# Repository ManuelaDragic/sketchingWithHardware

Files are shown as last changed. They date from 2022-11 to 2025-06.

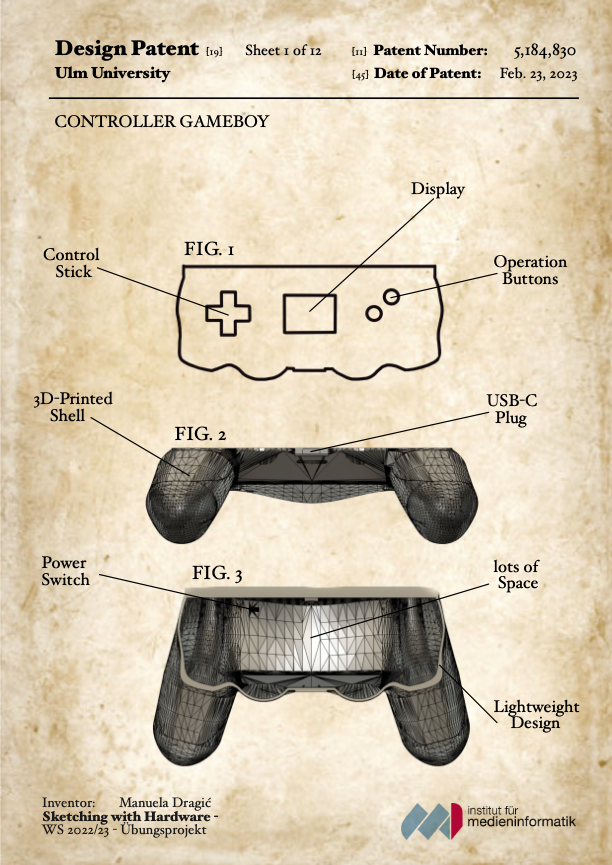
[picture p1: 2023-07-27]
content/posts/pictures/Poster.png

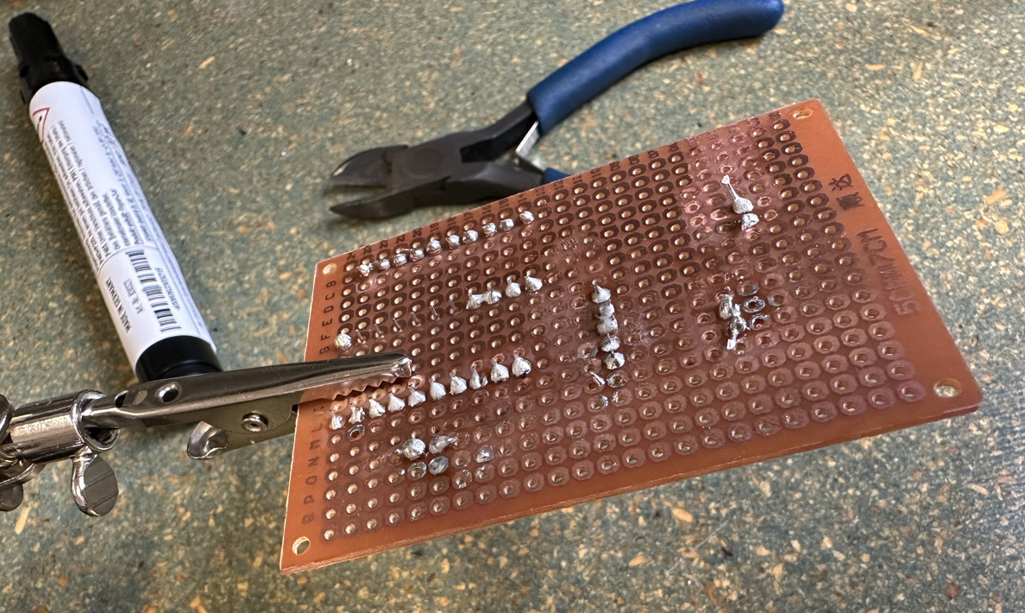
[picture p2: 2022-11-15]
content/posts/pictures/resultat.png

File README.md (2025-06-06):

# Sketching with Hardware

## Project of the applied subject in Media Informatics at Ulm University

During the winter semester 2022/23 and summer semester 2023. 
The blog can be found at: [(https://manueladragic.github.io/swh/)](https://manueladragic.github.io/swh/)

The files folder contains all the files necessary for rebuilding the WordClock Project.

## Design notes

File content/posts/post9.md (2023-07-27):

---
title: "02. Nachbauanleitung - WordClockanazier"
date: 2023-07-24T00:08:16+02:00
featured_image: "/pictures/wordclock.jpeg"
show_reading_time: true
draft: false
---

Eine WordClock ist eine Uhr, die anstelle von Zahlen Wörter oder Buchstaben verwendet, um die Uhrzeit anzuzeigen. 
Indem die WordClock mit einem intelligenten Kalender verknüpft wird, hilft sie dabei die Uhrzeit im Blick zu behalten und gleichzeitig über anstehende Termine informiert zu sein.
Daneben bietet der "WordClockanazier" weitere Features wie einen Farbwechselbutton, ein Ambient-Light und eine automatische Helligkeitsanpassung.
Einzelne Komponenten wie das Ambient-Light oder der Kalender können zudem beliebig ein- und ausgeschaltet werden. 
Betrieben wird die Uhr mit einem 5V Netzteil. 

Die Kosten für das Projekt betragen etwa 50 Euro.

{{< figure src="../pictures/Wordclock.jpeg" width="60%"height="60%">}}
{{< figure src="../pictures/Rahmen_oben(neu).jpeg" width="60%"height="60%">}}
{{< figure src="../pictures/Rahmen_rechts(neu).jpeg" width="60%"height="60%">}}
{{< figure src="../pictures/Rahmen_links(neu).jpeg" width="60%"height="60%">}}
{{< rawhtml >}} 
<video width=60% controls autoplay>
    <source src="../pictures/Funktionen.mp4" type="video/mp4">
    Your browser does not support the video tag.  
</video>
{{< /rawhtml >}}

</br>

### Bauteile, Zubehör und benötigte Programme

#### Technik:
- [ ] Wemos D1 mini 
- [ ] RTC Modul
- [ ] Knopf Batterie (für RTC Modul)
- [ ] 3m LED Stripe (60 LEDs pro Meter)
- [ ] 3x 4in1 Led Matrizen 
- [ ] USB auf Mikro USB Kabel (zum uploaden des Codes)

#### Materialien:
- [ ] Verschiedene Kabel (rot, schwarz, lila, blau, gelb, grün, braun)
- [ ] Schrumpfschläuche
- [ ] 3x Platine 2x8cm
- [ ] 1x Platine 6x8cm
- [ ] 3x Button groß (1cm x 1cm)
- [ ] 3x Buttonkappe (schwarz)
- [ ] Helligkeitssensor
- [ ] 2x Diode
- [ ] 1x Widerstand 2,2kOhm
- [ ] 1x Widerstand 4,7 kOhm
- [ ] 2x Widerstand 470 Ohm
- [ ] 1x ON/OFF Kippschalter
- [ ] 5V Adapter
- [ ] 5V 3A Netzteil
- [ ] 4 Senkkopfschrauben (3mm Durchmesser, 12mm lang)
- [ ] 4 Schrauben Fassungen (3mm Durchmesser, 5mm lang)

{{< figure src="../pictures/bauteile.jpeg" width="100%"height="80%">}}

#### Sonstiges:
- [ ] 2 x 3 mm dicke Spanplatte (mindestens 30x30cm groß)
- [ ] Durchsichtiges Filament (PLA)
- [ ] Schwarzes Filament (PLA)
- [ ] Doppelseitiges Klebeband
- [ ] 2 Komponenten Kleber

#### Geräte:
- [ ] großer 3D Drucker
- [ ] Lasercutter
- [ ] Lötkolben und -zubehör
- [ ] Bandsäge, Stichsäge oder eine andere Säge
- [ ] kleiner Schraubenzieher

#### Programme: 
- [ ] Arduino IDE
- [ ] Lightburn 
- [ ] (Fusion 360)
- [ ] (UltiMaker Cura)

#### Bauteile zu Cutten:
- [ ] Buchstabenplatte (3mm Spanplatte)
- [ ] LED Halterung (3mm Spanplatte)
- [ ] Holzfurnier (Buche)

#### Bauteile zu Drucken:
- [ ] Matrizenhalterung (Schwarz)
- [ ] Rahmen (Schwarz)
- [ ] Raster (Schwarz)
- [ ] Rasterfüllung (Durchsichtig)
- [ ] Rückplatte (Durchsichtig)

#### Zum testen:
- [ ] Steckplatine
- [ ] Jumperkabel

</br>

### Dateien zum Download

#### 3D-Modelle (STL's):
- <a href="https://github.com/ManuelaDragic/swh/blob/main/files/Matrizenhalterung.stl" download>Matrizenhalterung</a>
- <a href="https://github.com/ManuelaDragic/swh/blob/main/files/Word%20Clock%20Rahmen.stl" download>Rahmen</a>
- <a href="https://github.com/ManuelaDragic/swh/blob/main/files/WordClock%20Raster.stl"    download>Raster</a>
- <a href="https://github.com/ManuelaDragic/swh/blob/main/files/WordClock%20Rasterfüllung.stl" download>Rasterfüllung</a>
- <a href="https://github.com/ManuelaDragic/swh/blob/main/files/WordClock%20Rueckplatte.stl" download>Rückplatte</a>

#### Fusion360 Dateien:
- <a href="https://github.com/ManuelaDragic/swh/blob/main/files/Matrizenhalterung.f3d" download>Matrizenhalterung</a>
- <a href="https://github.com/ManuelaDragic/swh/blob/main/files/Word%20Clock%20Rahmen.f3d" download>Rahmen</a>
- <a href="https://github.com/ManuelaDragic/swh/blob/main/files/WordClock%20Raster.f3d"    download>Raster</a>
- <a href="https://github.com/ManuelaDragic/swh/blob/main/files/WordClock%20Rasterfüllung.f3d" download>Rasterfüllung</a>
- <a href="https://github.com/ManuelaDragic/swh/blob/main/files/WordClock%20Rueckplatte.f3d" download>Rückplatte</a>

#### Lightburn Datei:
- <a href="https://github.com/ManuelaDragic/swh/blob/main/files/Lasercut.lbrn2" download>Lasercut</a>

#### SVG:
- <a href="https://github.com/ManuelaDragic/swh/blob/main/files/Lasercut.svg" download>SVG Lasercut</a>

#### Code:
- <a href="https://github.com/ManuelaDragic/swh/blob/main/code/Kalender.gs" download>GoogleSkript</a>
- <a href="https://github.com/ManuelaDragic/swh/blob/main/code/WordClock/WordClock.ino" download>Arduino Code</a>
- <a href="https://github.com/ManuelaDragic/swh/blob/main/code/WordClock/WordClockFont.h" download>WordClock Font</a>

#### Links:
- <a href="https://script.google.com" download>Google Apps Skript</a>
- <a href="https://workspace.google.com/products/calendar/?hl=de#" download>Google Kalender</a>

</br>

### Lötplan

{{< figure src="../pictures/loetplan.jpg" width="100%"height="80%">}}

</br>

### Schritt für Schritt Bauanleitung

#### 1. Drucken der Bauteile

Zunächst einmal müssen die verschiedenen Bauteile gedruckt werden. Die zugehörigen STL's können auf meinem <a href="https://github.com/ManuelaDragic/swh/tree/main/files" download>Github</a> heruntergeladen werden, sind oben aber nochmals verlinkt.
Wichtig ist, dass für den Rahmen und die Rückplatte ein großer Drucker benötigt wird, da die Bauteile später ca. 25x35cm groß werden.
(Ich verwendete dazu den Creality CR10S5).
Der <a href="https://github.com/ManuelaDragic/swh/blob/main/files/Word%20Clock%20Rahmen.stl" download>Rahmen</a> des WordClockanizers, die <a href="https://github.com/ManuelaDragic/swh/blob/main/files/Matrizenhalterung.stl" download>Matrizenhalterung</a> und das <a href="https://github.com/ManuelaDragic/swh/blob/main/files/WordClock%20Raster.f3d"    download>Raster</a> werden mit schwarzem PLA gedruckt. Für die <a href="https://github.com/ManuelaDragic/swh/blob/main/files/WordClock%20Rasterfüllung.f3d" download>Rasterfüllung</a> und die <a href="https://github.com/ManuelaDragic/swh/blob/main/files/WordClock%20Rueckplatte.f3d" download>Rückplatte</a> wird durchsichtiges PLA verwendet.
Falls die Modelle noch angepasst werden sollen, können die jeweiligen Fusion360 Dateien ebenfalls oben heruntergeladen werden.

{{< figure src="../pictures/druck_schwarz.jpeg" width="100%"height="80%">}}
{{< figure src="../pictures/druck_durchsichtig.jpeg" width="100%"height="80%">}}

#### 2. Lasercutten

Danach werden die Buchstabenplatte und die LED-Stripe Halterung gecuttet. Dazu verwendete ich Lightburn. Zur leichteren Anpassung habe ich alle Linien des Cuts in eine <a href="https://github.com/ManuelaDragic/swh/blob/main/files/Lasercut.lbrn2" download>Datei</a> zusammengefügt. Für die Buchstabenplatte werden das innere Rechteck und die Buchstaben benötigt. Für die LED-Stripe Halterung werden das innere Rechteck und die schrägen Cuts an der linken und rechten Seite benötigt. Die jeweils anderen Linien können in Lightburn einfach ausgeblendet und ausgeschaltet werden.
Für die beiden Komponenten habe ich zwei 3mm dicke Spanplatten verwendet. Um sicher zu gehen sollten diese ca. 30x30cm groß sein. 

Die Vorderseite der Wordclock besteht aus ca 0,4 mm dickem Holzfurnier. Dazu werden zunächst zwei DIN A4 große Furniere zusammengeklebt. Ich verwendete die Farbe Buche, es kann jedoch jedes beliebige, helle Holz oder sogar Papier verwendet werden. 
Für die Vorderseite wird das äußere Rechteck und die Buchstaben benötigt.
Da das Furnier sehr dünn und spröde ist, muss sehr langsam und mit wenig Power gecuttet werden.
Testet eure Einstellungen zunächst am besten auf einem extra Furnier, indem ihr einen Buchstaben cuttet. So wisst ihr ob die Einstellungen die richtigen sind.

{{< figure src="../pictures/buchstabenplatte.jpeg" width="100%"height="60%">}}
{{< figure src="../pictures/furnier.jpeg" width="100%"height="60%">}}

#### 3. LED Matrizen

Anschließend nehmt ihr die LED-Matrizen zur Hand. Wir brauchen später 2 Reihem mit je 6 Matrizen, somit muss eine der 4er-Matrizen in zwei Hälften gecuttet werden. Dazu müssen die Matrizen einer 4er Reihe zunächst von der ihrer Platine genommen werden. Danach wird diese Platine in der Hälfte durgesägt. Ich habe dazu eine Bandsäge verwendet, ihr könnt jedoch auch eine andere Säge verwenden. 
Die beiden Hälften müssen dann jeweils an die anderen beiden 4er Reihen gelötet werden. Dabei ist wichtig, dass die Richtung der Matrizen beachtet wird. Im Anschluss können die einzelnen Matrizen wieder aufgesteckt werden.
Ihr sollten nun 2 Reihen mit je 6 Matrizen haben.

#### 4. Buchstabenplatte und Raster

Als nächstes muss der LED-Stripe auf die Platte gefädelt werden. Dies ist zwar mit etwas Arbeit verbunden, jedoch kann der Stripe so einfach ausgetauscht werden, falls er irgendwann kaputt gehen sollte. Zunächst muss der Stripe auf die richtige Länge geschnitten werden. Es werden genau 145 LED's benötigt. Wichtig ist dabei, dass die Richtung des Stripes beachtet wird und die hinteren LED's abgeschnitten werden, da der Stecker des Stripes noch benötigt wird. 
Nach dem durchfädeln sollten in jeder Reihe 11 LED's nach vorne zeigen. An den Seiten zeigt nun immer eine LED nach hinten, diese wird später für das Ambient Light verwendet.

{{< figure src="../pictures/led_halterung.jpeg" width="100%"height="60%">}}

Über die LED's wird dann das Raster gelegt. Damit nacher alles besser hält, habe ich doppelseitiges Klebeband verwendet, um die beiden Teile zusammen zu kleben. In die Löcher des Rasters werden dann die durchsichtigen Quadrate eingesetzt. Diese müssen nicht verklebt werden, da sie später zwischen den beiden anderen Platten eingeklemmt werden und somit nicht mehr verrutschen können.
Bei Bedarf können diese jedoch noch mit 2 Komponenten Kleber in das Raster geklebt werden. 
Anschließend wird dann die gecuttete Buchstabenplatte, erneut mit doppelseitigem Klebeband, auf das Raster geklebt.

{{< figure src="../pictures/raster.JPG" width="100%"height="100%">}}
{{< figure src="../pictures/platte.jpeg" width="100%"height="100%">}}

#### 5. Verkabelung

Der nächste Schritt ist das Verkabeln der Komponenten.
Testet zunächst ob ihr alles richtig verkabelt habt, indem ihr Jumperkabel und eine Steckplatine verwendet. Dazu verwendet ihr folgenden Plan:
{{< figure src="../pictures/loetplan.jpg" width="100%"height="80%">}}
Anbei ist noch einmal aufgelistet, welche PIN's der Komponenten mit den jeweiligen PIN's des ESP's verbunden werden:

##### RTC-Modul: 
SCL - D1

SDA - D2

VCC - 5V

GND - G

##### LED-Stripe

5V - 5V

DIN - D3

GND - G

##### LED-Matrix 1

CLK - D5

CS - D6

DATA - D7

GND - G

VCC - 5V

##### LED-Matrix 2

CLK - TX

CS - D4

DATA - D0

GND - G

VCC - 5V

##### 5V Adapter

GND - G

5V - 5V (mit zwischengeschaltetem Kippschalter)

Um die Kabel an den Adapter anzuschließen, schraubt ihr mit einem kleinen Schraubenzieher die Schrauben am Adapter ein wenig auf, steckt die Kabel rein und schraubt die Schrauben anschließend wieder gut zu.

{{< figure src="../pictures/verkabelung.PNG" width="100%"height="100%">}}

##### Buttons und Helligkeitssensor

Bei den Buttons ist wichtig, dass immer nur die zwei nebeneinanderliegenden oder die schräg-gegenüberliegenden Füßchen verwendet werden. Falls ihr euch nicht sicher seid, testet die Buttons zunächst mit einem Multimeter.

Der Button für den Farbwechsel befindet sich an einem seperaten Pin. Er wird an einer Seite an D8 am ESP angeschlossen, die andere Seite wird an VCC am ESP angeschlossen. Da dieser Button im Code entprellt wird, brauchen wir hierfür keinen Pulldown.

Die beiden anderen Buttons und der Helligkeitssensor werden an A0 angeschlossen. A0 ist der einzige analoge Pin an unserem ESP. Damit wir die verschiedenen Signale empfangen können, müssen wir vor die Buttons und vor den Helligkeitssensor verschiedene Widerstände schalten. Dadurch werden später beim analogRead im Code verschiedene Werte gelesen, wodurch unterschieden werden kann, ob sich die Helligkeit verändert hat oder ob ein Button, bzw. welcher Button gedrückt wurde. 
Wichtig ist dabei, dass jeweils die richtigen Widerstände verwendet werden.
Während Widerstände und Helligkeitssensor keine Richtung haben, müsst ihr bei den Dioden beachten, dass ihr sie in die richtige Richtung anschließt.

#### 6. Der Code

Der nächste Schritt ist das Programmieren. Dazu muss zunächst einmal die ArduinoIDE heruntergeladen werden. 
Danach muss das Board installiert werden. Dazu geht ihr in die Preferences und fügt bei "Additional boards manager URLs" folgende Zeile ein: 
http://arduino.esp8266.com/stable/package_esp8266com_index.json

{{< figure src="../pictures/boardmanager.png" width="100%"height="100%">}}

Anschließend muss das richtige Board ausgewählt werden. Unser Board ist das Lolin Wemos D1 mini - Board.
Dazu geht ihr im Menü auf Tools > Board > ESP8266 > LOLIN WEMOS D1 R2 & mini.

{{< figure src="../pictures/boardauswahl.png" width="100%"height="100%">}}

Danach verbindet ihr euren ESP mit einem USB Kabel an euren PC oder Laptop und wählt unter Port den entsprechenden USB Port aus.
Nun geht es an den Code des Wordclockanizers.
Der <a href="https://github.com/ManuelaDragic/swh/tree/main/code/WordClock" download>Programmcode</a> kann ebenfalls einfach im GitHub-Repo heruntergeladen werden. Beachtet jedoch, dass ihr den Code und die Font im gleichen Ordner abspeichern müsst. Der Ordner muss den selben Namen wie unser Programmcode haben, in unserem Fall ist das "WordClock".

#### 6.1 Libraries

Für unser Programm müssen zunächst einige Libraries eingebunden werden.
```cpp
#include <Wire.h>
#include <RTClib.h>   
#include <FastLED.h>

#include <MD_Parola.h>
#include <MD_MAX72xx.h>
#include <SPI.h>

#include <Bounce2.h>

#include <ESP8266WiFi.h>
#include <ESP8266HTTPClient.h>
#include <Arduino.h>
 ```
Diese Libraries können einfach über den Library Manager in der Arduino IDE heruntergeladen werden. Sucht dazu einfach im Suchfeld nach den jeweiligen Namen. 

{{< figure src="../pictures/libraries.png" width="100%"height="100%">}}

Zudem werden hier die Fonts für die LED Matrizen eingebunden. Falls ihr später eigene Fonts einbinden möchtet, könnt ihr das an dieser Stelle tun.

#### 6.2 Eigene Font erstellen

Falls ihr später auf euren LED-Matrizen euren eigenen Font verwenden wollt, könnt ihr euch diesen einfach auf folgender Seite zusammenklicken:
https://pjrp.github.io/MDParolaFontEditor

Durch Auswahl der Quadrate können die Buchstaben dann einfach durch klicken der jeweiligen LED's erstellt werden.
Anschließend gebt ihr auf der linken Seite noch einen Namen für euren Font ein und exportiert dann alles.
Die fertige Datei legt ihr dann in den Ordner zu eurem Code.
Zuletzt muss die Datei dann nur noch im Arduino Code eingebunden werden.

```cpp
#include "Parola_Fonts_data.h"
#include "WordClockFont.h"
```

#### 6.3 WIFI Connection 

Als nächstes müsst ihr im Code noch die WLAN Einstellungen anpassen.
```cpp
const char* ssid = "YOUR_SSID";
const char* password = "YOUR_PASSWORD";
 ```

YOUR_SSID muss natürlich mit dem Namen und YOUR_PASSWORD mit dem Passwort des eigenen WLANS ersetzt werden.

#### 6.4 Kalenderdaten

##### Für Apple-Kalender User
Da Apple das auslesen der Kalenderdaten nicht so einfach macht, müsst ihr hier etwas tricksen. Um später die eigenen Apple-Kalenderdaten anzeigen zu können, müsst ihr euern Apple Kalender von einem Google Kalender abonnieren. 
Dazu muss man sich zunächst über einen Laptop oder PC mit seinem Google-Acoout beim <a href="https://workspace.google.com/products/calendar/?hl=de#" download>Google Kalender</a> anmelden. 
Anschließend kann auf der linken Seite unter  "Weitere Kalender > + > Per URL"  ein Kalender abonniert werden.

{{< figure src="../pictures/kalender_abonnieren.png" width="100%"height="100%">}}

Jetzt öffnet ihr auf eurem Handy euren Apple Kalender und klickt unten in der Mitte auf "Kalender".
Dort wählt ihr den Kalender aus, den ihr teilen möchtet und klickt auf das i.
Der Kalender muss dann noch auf öffentlich gestellt werden. Unter "Link teilen" könnt ihr den Link anschließend kopieren und in das Feld "URL des Kalenders" im Google Kalender eintragen. 
ACHTUNG! Das bedeutet, dass jetzt theoretisch jeder auf euren Kalender zugreifen kann.

{{< figure src="../pictures/link.png" width="60%"height="60%">}}
{{< figure src="../pictures/url.png" width="100%"height="100%">}}

##### Für Google-Kalender User
Falls ihr bereits einen Google-Kalender verwendet, könnt ihr diese Schritte natürlich überspringen.

Anschließend geht ihr auf <a href="https://script.google.com" download>script.google.com</a> und meldet euch dort ebenfalls mit eurem Google Account an. Dort klickt ihr dann auf "neues Projekt".

{{< figure src="../pictures/neuesProjekt.png" width="100%"height="100%">}}

Gebt dem Projekt einen Namen und kopiert folgenden <a href="https://github.com/ManuelaDragic/swh/blob/main/code/Kalender.gs" download>Code</a> hinein:

```js
function doGet(e) {
  
  var calendars = CalendarApp.getAllCalendars();
  
  if (calendars == undefined) {
    Logger.log("No data");
    return ContentService.createTextOutput("no access to calendar");
  }
  
  var calendars_selected = [];
  for (var i = 0; i < calendars.length; i++) {
    if (calendars[i].isSelected()) {
      calendars_selected.push(calendars[i]);
      Logger.log(calendars[i].getName());
    }
  }
  
  Logger.log("Old: " + calendars.length + " New: " + calendars_selected.length);
  const now = new Date();
  var start = new Date(); start.setHours(0, 0, 0);      // start at midnight
  const oneday = 24*3600000;                            // milliseconds
  const stop = new Date(start.getTime() + 7 * oneday);  // appointments for the next 7 days
  var events = mergeCalendarEvents(calendars_selected, start, stop);

  var str = '';
  for (var i = 0; i < events.length; i++) {  
    var event=events[i];    
    var myStatus = event.getMyStatus();
    
    switch(myStatus) {
      case CalendarApp.GuestStatus.OWNER:
      case CalendarApp.GuestStatus.YES:
      case CalendarApp.GuestStatus.NO:  
      case CalendarApp.GuestStatus.INVITED:
      case CalendarApp.GuestStatus.MAYBE:
      default:
        break;
    }
    
    // format date and time output
    const options1 = {
      weekday: "short",
      year: "numeric",
      month: "short",
      day: "numeric",
    };

    const options2 = {
      hour: "numeric",
      minute: "numeric",
    };

    // create output string
    str += new Date(event.getStartTime()).toLocaleString("de-DE", options1) +  ' ';
    if (event.isAllDayEvent()) {
      str += '(Ganztägig) ';
    }
    else {
      str += new Date(event.getStartTime()).toLocaleString("de-DE", options2) +  '-' 
      + new Date(event.getEndTime()).toLocaleString("de-DE", options2) +  ' ';
    }
    str += event.getTitle() + " \n";

  }

  // replace vowels
  str = str.replace(/Ä/g, "AE");
  str = str.replace(/Ö/g, "OE");
  str = str.replace(/Ü/g, "UE");
  str = str.replace(/ä/g, 'ae');
  str = str.replace(/ö/g, 'oe');
  str = str.replace(/ü/g, 'ue');

  // return output String
  return ContentService.createTextOutput(str);
}

function mergeCalendarEvents(calendars, startTime, endTime) {
  var params = { start:startTime, end:endTime, uniqueIds:[] };
  return calendars.map(toUniqueEvents_, params)
                  .reduce(toSingleArray_)
                  .sort(byStart_);
}

function toCalendars_(id) { 
  return CalendarApp.getCalendarById(id); 
}

function toUniqueEvents_ (calendar) {
  return calendar.getEvents(this.start, this.end)
                 .filter(onlyUniqueEvents_, this.uniqueIds);
}

function onlyUniqueEvents_(event) {
  var eventId = event.getId();
  var uniqueEvent = this.indexOf(eventId) < 0;
  if(uniqueEvent) this.push(eventId);
  return uniqueEvent;
}

function toSingleArray_(a, b) { 
  return a.concat(b) 
}

function byStart_(a, b) {
  return a.getStartTime().getTime() - b.getStartTime().getTime();
}

```
Speichert den Code ab und drückt dann auf "Bereitstellen > Neue Bereitstellung"

{{< figure src="../pictures/bereitstellen.png" width="100%"height="100%">}}

Als Typ wählt ihr dann "Web-App" aus und bei Zugriffsrechte "Jeder". Anschließend klickt ihr auf "bereitstellen".
Jetzt erscheinen eine Bereitstellungs-ID und eine URL. Wenn ihr auf diese URL klickt und alles funktioniert hat, sollten nun eure Kalenderdaten der nächsten 7 Tage angezeigt werden.

{{< figure src="../pictures/kalenderdaten_desktop.png" width="100%"height="100%">}}

Kopiert nun die URL und fügt sie im Arduino Code in die Methode "getKalenderData()" bei "YOUR_URL" ein:

```cpp
void getKalenderData() {

  ... 
  client.connect("script.googleusercontent.com", 443);
  String url = "YOUR_URL";
  ...
}
```

#### 6.5 Uhrzeit des RTC-Moduls stellen

Als letzten Schritt müsst ihr jetzt noch die Uhrzeit eurer Uhr richtig stellen.
Dazu könnt ihr entweder die aktuelle Zeit über eure Konsole holen, oder manuell eine Uhrzeit angeben.
Falls ihr die erste Variante verwenden möchtet, dann verzögert sich eure Uhrzeit um die Länge des Uploads eures Codes, da die Zeit so auf die Zeit des Uploadbeginns gesetzt wird.
Verwendet ihr die zweite Variante, so müsst ihr den Code zunächst mit einer Zeit 2-3 Minuten im Voraus Uploaden, um dann zur genauen Zeit den reset Button an eurem ESP drücken zu können. Damit setzt ihr dann quasie "zur richtigen Zeit" eure eingegebene Uhrzeit.
Je nachdem welche Variante ihr verwendet, müsst ihr die jeweilige Zeile in der Methode "setup()" im Code einkommentieren.
Anschließend ladet ihr den Code dann ein zweites Mal hoch, dieses Mal jedoch wieder mit der auskommentierten Zeile, sodass eure Uhrzeit nicht jedes mal beim reset zurückgesetzt wird.

```cpp
void setup() {
  
  ...

  // ----- RTC Modul -------
  //
  rtc.begin();

  // Falls das DS3231-Modul nicht korrekt erkannt wird
  if (!rtc.begin()) {
    Serial.println("Konnte RTC nicht finden!");
    while (1);
  }

  // Falls das DS3231-Modul keine Stromversorgung hatte und dadurch die Zeit verloren hat, kann die Zeit hiermit festgelegt werden
  // Beim ersten upload muss diese Zeile eingefügt werden
  // Anschließend muss der Code nochmals mit auskommentierter Zeile geuploaded werden
  // rtc.adjust(DateTime(F(__DATE__), F(__TIME__)));

  // Oder die genaue Zeit kann hier im Format (JJJJ, MM, TT, hh, mm, ss) angegeben werden.
  // Wenn genau zu dieser Zeit reset am ESP gedrückt wird, so wird die Uhr genau auf diesen Anfangswert gestellt
  // rtc.adjust(DateTime(2023, 6, 25, 11, 59, 0));

  ...
```

Wenn am weiteren Code nichts mehr verändert werden soll, kann dieser nun einfach auf den ESP geladen werden. 
Dazu klickt ihr in eurer Arduino IDE auf den Pfeil im oberen linken Eck.
Wenn alles richtig gemacht wurde, wird euer Code nun hochgeladen und ihr könnt euer Programm testen.

#### 7. Das Programm

Um den Code ein wenig verständlicher zu machen, werden anbei noch einige wichtige Parts erklärt

#### 7.1 PINS und Hardware definieren

Zunächst müssen PINS und Hardware definiert werden. Falls ihr eine andere Verkabelung verwenden wollt, so müssen die Pins entsprechend im Code angepasst werden.

Für die LED-Matrizen gibt es 4 gängige Hardwaretypen: PAROLA_HW, GENERIC_HW, ICSTATION_HW und FC16_HW. In meinem Fall war das FC16_HW.
Falls eure Matrizen den Text komisch oder falschrum anzeigen, versucht zunächst einen anderen Hardwaretyp.
MAX_DEVICES definiert , wie viele 8x8 LED-Matrizen sich in einer Reihe befinden.
NUM_LEDS definiert die Anzahl der LEDs von eurem LED-Stripe, LED_TYPE den Typen des LED-Stripes.

```cpp
// LED Stripe
#define DATA_PIN    D3
#define LED_TYPE    WS2812
#define COLOR_ORDER GRB
#define NUM_LEDS    145  

// Matrizes
#define HARDWARE_TYPE MD_MAX72XX::FC16_HW
#define MAX_DEVICES 6

// matrix1
#define M1_CLK_PIN   D5
#define M1_CS_PIN    D6
#define M1_DATA_PIN  D7

// matrix2
#define M2_CLK_PIN   TX 
#define M2_CS_PIN    D4 
#define M2_DATA_PIN  D0

// Buttons 
#define BUTTON_PIN  D8
#define ANALOG_PIN  A0
```

#### 7.2 RTC-Modul und LED-Stripe

Um auf die Uhrzeit zuzugreifen und die LED's entsprechend zu schalten, muss die Uhrzeit zunächst vom RTC Modul ausgelesen werden.
Die Methode "showTime()" holt Datum und Uhrzeit vom RTC-Modul und checkt anschließend, welche LED's zur jeweiligen Zeit ein- und ausgeschaltet werden sollen.

```cpp
// zeigt die aktuelle Uhrzeit an
void showTime() {

  // Datum und Uhrzeit von RTC Modul auslesen
  DateTime jetzt = rtc.now();
  
  int Jahr = jetzt.year();
  int Monat = jetzt.month();
  int Tag = jetzt.day();
  int Stunde = jetzt.hour();
  int Minute = jetzt.minute();
  int Sekunde = jetzt.second();
  int Wochentag = jetzt.dayOfTheWeek();
  float Temperatur = rtc.getTemperature();

  // in das passende 12 Stunden Format bringen
  if(Stunde >= 12)
  {
      Stunde -= 12;
  }
  if(Minute >= 25)
  {
      Stunde++;
  }
  if(Stunde == 12)
  {
      Stunde = 0;
  }

  // "Es ist" ausgeben
    leds[1] = color;
    leds[2] = color;
    leds[4] = color;
    leds[5] = color;
    leds[6] = color;

  // "Uhr" anzeigen
  if(Minute < 5)
  {
    Serial.print("UHR ");
    leds[133] = color;
    leds[134] = color;
    leds[135] = color;
  }

  // Wochentag anzeigen
  Serial.print("Wochentag: ");
  Serial.print(Wochentag);
  switch (Wochentag) {
    // Montag
    case 1:
      leds[8] = color;
      leds[9] = color;
      break;
    // Dienstag
    case 2:
      leds[10] = color;
      leds[11] = color;
      break;
    // Mittwoch
    case 3:
      leds[22] = color;
      leds[23] = color;
      break;
    // Donnerstag
    case 4:
      leds[20] = color;
      leds[21] = color;
      break;
    // Freitag
    case 5:
      leds[18] = color;
      leds[19] = color;
      break;
    // Samstag
    case 6:
      leds[16] = color;
      leds[17] = color;
      break;
    // Sonntag
    case 0:
      leds[14] = color;
      leds[15] = color;
      break;
    default:
      Serial.println("Ungültiger Wochentag");
      break;
  }

  // Stunde anzeigen
  switch(Stunde) {
    case 0:
      //Zwölf
      Serial.print("ZWÖLF ");
      leds[127] = color;
      leds[128] = color;
      leds[129] = color;
      leds[130] = color;
      leds[131] = color;
      break;
    case 1:
      //EIN(S)
      Serial.print("EIN");
      leds[93] = color;
      leds[94] = color;
      leds[95] = color;
      // sobald es 5 nach 1 ist muss das s mitleuchten
      if(Minute > 4){
        leds[92] = color;
      }
      break;
    case 2:
      //Zwei
      Serial.print("ZWEI ");
      leds[85] = color;
      leds[86] = color;
      leds[87] = color;
      leds[88] = color;
      break;
    case 3:
      //Drei
      Serial.print("DREI ");
      leds[97] = color;
      leds[98] = color;
      leds[99] = color;
      leds[100] = color;
      break;
    case 4:
      //Vier
      Serial.print("VIER ");
      leds[104] = color;
      leds[105] = color;
      leds[106] = color;
      leds[107] = color;
      break;
    case 5:
      //Fünf
      Serial.print("FÜNF ");
      leds[80] = color;
      leds[81] = color;
      leds[82] = color;
      leds[83] = color;
      break;
    case 6:
      //Sechs
      Serial.print("SECHS ");
      leds[115] = color;
      leds[116] = color;
      leds[117] = color;
      leds[118] = color;
      leds[119] = color;
      break;
    case 7:
      //Sieben
      Serial.print("SIEBEN ");
      leds[121] = color;
      leds[122] = color;
      leds[123] = color;
      leds[124] = color;
      leds[125] = color;
      leds[126] = color;
      break;
    case 8:
      //Acht
      Serial.print("ACHT ");
      leds[109] = color;
      leds[110] = color;
      leds[111] = color;
      leds[112] = color;
      break;
    case 9:
      //Neun
      Serial.print("NEUN ");
      leds[137] = color;
      leds[138] = color;
      leds[139] = color;
      leds[140] = color;
      break;
    case 10:
      //Zehn
      Serial.print("ZEHN ");
      leds[140] = color;
      leds[141] = color;
      leds[142] = color;
      leds[143] = color;
      break;
    case 11:
      //Elf
      Serial.print("ELF ");
      leds[78] = color;
      leds[79] = color;
      leds[80] = color;
      break;
  }

  // Minuten anzeigen
  if(Minute >= 5 && Minute < 10)
  {
      // Fünf
      Serial.print("FÜNF ");
      leds[27] = color;
      leds[28] = color;
      leds[29] = color;
      leds[30] = color;
      // Nach
      Serial.print("NACH ");
      leds[61] = color;
      leds[62] = color;
      leds[63] = color;
      leds[64] = color;

  }
  else if(Minute >= 10 && Minute < 15)
  {
      // Zehn
      Serial.print("ZEHN ");
      leds[44] = color;
      leds[45] = color;
      leds[46] = color;
      leds[47] = color;
      // Nach
      Serial.print("NACH ");
      leds[61] = color;
      leds[62] = color;
      leds[63] = color;
      leds[64] = color;
  }
  else if(Minute >= 15 && Minute < 20)
  {
      // Viertel
      Serial.print("VIERTEL ");
      leds[53] = color;
      leds[54] = color;
      leds[55] = color;
      leds[56] = color;
      leds[57] = color;
      leds[58] = color;
      leds[59] = color;
      // Nach
      Serial.print("NACH ");
      leds[61] = color;
      leds[62] = color;
      leds[63] = color;
      leds[64] = color;
  }
  else if(Minute >= 20 && Minute < 25)
  {
      // Zwanzig
      Serial.print("ZWANZIG ");
      leds[37] = color;
      leds[38] = color;
      leds[39] = color;
      leds[40] = color;
      leds[41] = color;
      leds[42] = color;
      leds[43] = color;
      // Nach
      Serial.print("NACH ");
      leds[61] = color;
      leds[62] = color;
      leds[63] = color;
      leds[64] = color;
  }
  else if(Minute >= 25 && Minute < 30)
  {
      // Fünf
      Serial.print("FÜNF ");
      leds[27] = color;
      leds[28] = color;
      leds[29] = color;
      leds[30] = color;
      // Vor
      Serial.print("VOR ");
      leds[69] = color;
      leds[70] = color;
      leds[71] = color;
      // Halb
      Serial.print("HALB ");
      leds[73] = color;
      leds[74] = color;
      leds[75] = color;
      leds[76] = color;

  }
  else if(Minute >= 30 && Minute < 35)
  {
      // Halb
      Serial.print("HALB ");
      leds[73] = color;
      leds[74] = color;
      leds[75] = color;
      leds[76] = color;

  }
  else if(Minute >= 35 && Minute < 40)
  {
      // Fünf
      Serial.print("FÜNF ");
      leds[27] = color;
      leds[28] = color;
      leds[29] = color;
      leds[30] = color;
      // Nach
      Serial.print("NACH ");
      leds[61] = color;
      leds[62] = color;
      leds[63] = color;
      leds[64] = color;
      // Halb
      Serial.print("HALB ");
      leds[73] = color;
      leds[74] = color;
      leds[75] = color;
      leds[76] = color;

  }
  else if(Minute >= 40 && Minute < 45)
  {
      // Zwanzig
      Serial.print("ZWANZIG ");
      leds[37] = color;
      leds[38] = color;
      leds[39] = color;
      leds[40] = color;
      leds[41] = color;
      leds[42] = color;
      leds[43] = color;
      // Vor
      Serial.print("VOR ");
      leds[69] = color;
      leds[70] = color;
      leds[71] = color;
  }
  else if(Minute >= 45 && Minute < 50)
  {
      // Viertel
      Serial.print("VIERTEL ");
      leds[53] = color;
      leds[54] = color;
      leds[55] = color;
      leds[56] = color;
      leds[57] = color;
      leds[58] = color;
      leds[59] = color;
      // Vor
      Serial.print("VOR ");
      leds[69] = color;
      leds[70] = color;
      leds[71] = color;
  }
  else if(Minute >= 50 && Minute < 55)
  {
      // Zehn
      Serial.print("ZEHN ");
      leds[44] = color;
      leds[45] = color;
      leds[46] = color;
      leds[47] = color;
      // Vor
      Serial.print("VOR ");
      leds[69] = color;
      leds[70] = color;
      leds[71] = color;
  
  }
  else if(Minute >= 55 && Minute < 60)
  {
      // Fünf
      Serial.print("FÜNF ");
      leds[27] = color;
      leds[28] = color;
      leds[29] = color;
      leds[30] = color;
      // Vor
      Serial.print("VOR ");
      leds[69] = color;
      leds[70] = color;
      leds[71] = color;
  }
  
  FastLED.show();
}
```

#### 7.3 Kalenderdaten

Die Kalenderdaten werden mit Hilfe eines <a href="https://github.com/ManuelaDragic/swh/blob/main/code/Kalender.gs" download>GoogleSkripts</a> ausgelesen und als String gespeichert.
Da die LED-Matrizen keine Umlaute anzeigen können, werden diese hier noch vorher herausgefiltert. Zusätzlich wird der String in Großbuchstaben umgewandelt. Durch anschließendes Bereitstellen einer WebApp können die Kalenderdaten dann mit einem einfachen HTTP-Request abgefragt werden. 
Beim Einschalten der Uhr werden die Daten das Erste mal abgefragt. Der empfangene String wird dann in Substrings unterteilt und anschließend auf den LED-Matrizen angezeigt.

```cpp
void getKalenderData() {

  // HTTP-Anfrage senden
  WiFiClientSecure client;
  HTTPClient http;
  client.setInsecure();
  client.connect("script.googleusercontent.com", 443);
  String url = "YOUR_URL";
  http.setTimeout(20000);
  http.setFollowRedirects(HTTPC_STRICT_FOLLOW_REDIRECTS);
  http.begin(client, url); 
  int httpCode = http.GET();
  Serial.println(httpCode);

  // Daten in payload String speichern
  if (httpCode == 200) {
    Serial.println("Getting calendar");
    payload = http.getString();
  }

  // String in Substrings splitten
  while (payload.length() > 0)
  {
    // an jeder Zeile trennen und als Substring speichern
    int index = payload.indexOf('\n');

    if (index == -1) 
    {
      strs[StringCount] = payload;
      strs[StringCount].toUpperCase();
      strs[StringCount].toCharArray(events[StringCount], 60);
      Serial.println(strs[StringCount]);
      Serial.println(events[StringCount]);
      StringCount++;
      break;
    }

    else
    {
      strs[StringCount] = payload.substring(0, index);
      strs[StringCount].toUpperCase();
      strs[StringCount].toCharArray(events[StringCount], 60);
      Serial.println(strs[StringCount]);
      Serial.println(events[StringCount]);
      StringCount++;
      payload = payload.substring(index+1);
    }
  }
  
  http.end();
}
```

Um immer aktuelle Kalenderdaten angezeigt zu bekommen, werden im Loop zwei Uhrzeiten gecheckt, zu denen die Daten aktualisiert werden.

```cpp
loop() {
    ...
    // Kalenderdaten um 2 und 12 Uhr aktualisieren
    if (now.hour() == 1 && now.minute() == 0 && now.second() == 0 || now.hour() == 12 && now.minute() == 0 && now.second() == 0) {
        getKalenderData();
    }
}
```

#### 7.4 LED-Matrizen 

Die Kalenderdaten werden als Lauftext auf den LED-Matrizen angezeigt.
Dabei wird der erste Termin auf der ersten Matrix angezeigt, der zweite auf der zweiten Matrix. Anschließend wechselt der zweite Termin auf die erste Matrix und der nächste Termin erscheint auf der zweiten Matrix.

```cpp
void runMatrix() {
  
  // Display Text anzeigen
  matrix1.setIntensity(brightnessMatrix); 
  matrix2.setIntensity(brightnessMatrix);

  // Wenn matrix1 fertig auf true setzen
  if (matrix1.displayAnimate()) {
    matrix1Fertig = true;
  }

  // Wenn matrix2 fertig auf true setzen
  if (matrix2.displayAnimate()) {
    matrix2Fertig = true;
  }

  // Wenn beide fertig sind, neuen Text anzeigen
  if (matrix1Fertig && matrix2Fertig) {
    
    // (Zum anpassen: erster Wert: Text, zweiter Wert = Start Position, Dritter Wert = Geschwindigkeit, Vierter Wert = Pause am Ende, Fünfter Wert = Animation Rein, Sechster Wert = Animation Raus)
    // Positionen: PA_LEFT, PA_RIGHT, PA_CENTER
    // Animationsliste: PA_PRINT, PA_SCROLL_UP, PA_SCROLL_DOWN, PA_SCROLL_LEFT, PA_SCROLL_RIGHT, PA_SCROLL_UP_LEFT, PA_SCROLL_UP_RIGHT, PA_SCROLL_DOWN_LEFT, PA_SCROLL_DOWN_RIGHT,
    //                  PA_SPRITE, PA_SLICE, PA_MESH, PA_FADE, PA_DISSOLVE, PA_BLINDS, PA_RANDOM, PA_WIPE, PA_WIPE_CURSOR, 
    //                  PA_SCAN_HORIZ, PA_SCAN_HORIZX, PA_SCAN_VERT, PA_SCAN_VERTX, PA_OPENING, PA_OPENING_CURSOR, PA_CLOSING, PA_CLOSING_CURSOR, PA_GROW_UP, PA_GROW_DOWN 
    matrix1.displayText (events[i], PA_LEFT, speed, 0, PA_SCROLL_LEFT, PA_SCROLL_LEFT);
    //  set up for next text
    i++; 

    if (i == StringCount) {
      i = 0;
    } 

    matrix2.displayText (events[i], PA_LEFT, speed, 0, PA_SCROLL_LEFT, PA_SCROLL_LEFT);
      
    matrix1Fertig = false;
    matrix2Fertig = false;

    delay (1000);
  }
}
```
"displayAnimate()" startet die Animation des Lauftextes und gibt true zurück, wenn diese durchgelaufen ist.
Erst wenn beide Matrizen durchgelaufen sind werden dann neue Daten angezeigt.
"displayText()" zeigt den Text mit einer Startposition, einer Geschwindigkeit, einem Delay und einer ein- und auslauf Animation an.
Die Animationen können beliebig geändert werden. Eine Liste von Animationen ist im Kommentar gegeben.

#### 7.5 Buttons und Helligkeitssensor

Die Buttons und der Helligkeitssensor werden kontinuierlich im loop überprüft. Der Farbwechsel Button ist an einem digitalen Pin angeschlossen und wird mit einem Debouncer entprellt, sodass bei einem Klick auch nur einmal reagiert wird.
Die anderen beiden Buttons und der Helligkeitssensor befinden sich an einem analogen Pin. 
Mit "analogRead()" wird des Wert des analogen PIN's ständig überprüft. Durch Veränderung des Wertes werden dann z.B. ein Knopfdruck oder eine Änderung der Helligkeit registriert.

```cpp
void loop() {

  ...

  // ------ Farbwechsel Button ------
  //
  debouncer.update();       // Entprellten Wert aktualisieren
  if (debouncer.rose()) {
    changeColor();
  }

  // ------ Helligkeit anpassen ------
  //
  // Helligkeit herabsetzen
  if (analogRead(ANALOG_PIN) < 300) {
    brightnessDown = true;
  }

  // Helligkeit erhöhen
  if (analogRead(ANALOG_PIN) < 500 && analogRead(ANALOG_PIN) > 300) {
    brightnessDown = false;
  }

  // ------ Matrizen Button ------
  //
  // AN/AUS
  if(buttonMatrizenStatus) {
    runMatrix();
  }

  if (!matrizenStatus) {
    if (analogRead(ANALOG_PIN) > 1000) {
      buttonMatrizenStatus = !buttonMatrizenStatus;
      if(!buttonMatrizenStatus) {
        matrix1.displayClear();
        matrix2.displayClear();
        matrix1.displayReset();
        matrix2.displayReset();
        i = 0;
      }
      matrizenStatus = true;
      matrizenTimer = millis();
    }

    // ------ Backlight Button ------
    //
    // AN/AUS
    else if (analogRead(ANALOG_PIN) > 600) {
      buttonBacklightOff = !buttonBacklightOff;
      matrizenStatus = true;
      matrizenTimer = millis();
    }

  } 

  // nur auf einen Druck reagieren
  else {
    if(analogRead(ANALOG_PIN) < 500 && ((millis() - matrizenTimer) > 500)) {
      matrizenStatus = false;
    }
  }

  ...
  
}
```

#### 8. Löten

Wenn das uploaden geklappt hat und alle Kompononten funktioniern, könnt ihr nun mit dem Löten beginnen.
Nehmt nochmal den Lötplan zur Hand und lötet die Kabel nach und nach an eure Komponenten.

ACHTUNG! Achtet darauf, dass ihr vor dem Löten den Strom abzieht und die Batterie des RTC-Moduls entnehmt.

Für den ESP und das RTC Modul habe ich die 6x8cm große Platine verwendet. Lötet das RTC Modul so an, dass die Batterie nach oben zeigt. So könnt ihr diese später austauschen, falls sie leer gehen sollte.
Für die Buttons habe ich je eine der drei 2x8cm Platinen verwendet.
Damit die Buttons später in die Aussparungen im Rahmen passen, müsst ihr jetzt noch beachten, dass ihr die Buttons und den Helligkeitssensor an die richtige Stelle der Platine lötet. (Die Buttons werden jeweils in das untere Eck der Platine platziert). 
Außerdem muss beachtet werden, dass alle Kabel die richtige Länge besitzen.
Legt die Teile am besten vorher in euren Rahmen und testet, wie lang die Kabel ca. sein müssen.
Der ON/OFF-Kippschalter wird erst nach zusammenbauen der Uhr angelötet, da dieser von Außen auf den Rahmen gesteckt werden muss.

Überprüft vor dem Anschließen des Stroms nochmal alle Lötstellen und achtet darauf, dass ihr keinen Kurzschluss verursacht habt, indem ihr aus Versehen Lötstellen verbunden habt. 

#### 9. Zusammenbau

Zu Schluss muss das Projekt dann noch zusammengebaut werden.
Dazu setzt ihr zunächst die Matrizenhalterung in den Rahmen ein. In die Matrizenhalterung werden dann die LED-Matrizen geseteckt. Die Kabel führt ihr nach oben durch die Lücke in das Innere des Rahmens. Die Technik befindet sich so hinter der zuvor gebauten Buchstabenplatte. Setzt die Platinen nach folgendem Plan vorsichtig in die jeweiligen Halterungen ein. 

{{< figure src="../pictures/aufbau.jpg" width="100%"height="80%">}}

Der Helligkeitssensor sollte dabei etwas aus dem Rahmen herausschauen, sodass er die Helligkeit auch richtig messen kann.
Die Platinen der Buttons klebt ihr dann mit 2 Komponenten Kleber in die jeweiligen Lücken im Rahmen.
Anschließend klebt ihr die Buchstabenplatte mit doppelseitigem Klebeband in den Rahmen der Uhr. Wenn alles passt, sollten Rahmen, Matrizen und Buchstabenplatte nun bündig abschließen und somit eine ebene Fläche bilden.

Wenn alles passt könnt ihr dann mit einem Lötkolben die 4 Schraubenfassungen in die Löcher auf der Rückseite des Rahmens drücken.
Als Letztes kann dann die durchsichtige Rückplatte mit dem Rahmen verschraubt werden.

Zu guter Letzt kann dann noch das Furnier auf die Vorderseite der Uhr geklebt werden - Und fertig ist der selbstgebaute WordClockanizer.

{{< figure src="../pictures/schritt1.jpeg" width="60%"height="60%">}}
{{< figure src="../pictures/schritt2.jpeg" width="60%"height="60%">}}
{{< figure src="../pictures/schritt3.jpeg" width="60%"height="60%">}}
{{< figure src="../pictures/schritt4.jpeg" width="60%"height="60%">}}
{{< figure src="../pictures/schritt5.jpeg" width="60%"height="60%">}}
{{< figure src="../pictures/clock.jpeg" width="60%"height="60%">}}

### Lizensierung

<br />Dieses Werk ist lizenziert unter einer <a rel="license" href="http://creativecommons.org/licenses/by/4.0/">Creative Commons Namensnennung 4.0 International Lizenz</a>.

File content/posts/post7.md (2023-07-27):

---
title: "07. Abschlusspräsentation"
date: 2023-03-05T14:54:18+01:00
featured_image: "/pictures/Gameboy.png"
show_reading_time: true
draft: false
---

### Zusammenfassung und Rückblick

Zu Beginn des ersten Semesters von Sketching with Hardware sollten wir uns ein kleines Projekt aussuchen und es den Anderen präsentieren. Ich entschied mich für die "Word-Clock". 
{{< figure src="../pictures/WordClock.jpg" width="40%"height="60%">}}
Dabei sollten wir vorallem auf unsere bisherigen Fähigkeiten eingehen. Wie ich feststellte, hatte ich zum damaligen Zeitpunkt noch keinerlei Erfahrung im Laser Cutten, Löten und programmieren mit Arduinos. 
Aus diesem Grund konnte ich die Schwierigkeit des Projektes nicht einschätzen, war aber ganz zuversichtlich, dass ich das Projekt mit einer genauen Anleitung und ein wenig Hilfe umsetzen könnte.
Während des Semesters erlernten wir dann in den verschiedenen Laboren alle nötigen Fähigkeiten, um unsere Projekte irgendwann mal selbst nachbauen zu können. 
Rückblickend kann ich sagen, dass ich mein Projekt nun ohne große Probleme selbst auf die Beine stellen könnte. Löten, Laser Cutten und ein wenig programmieren sind jetzt kein Problem mehr und meiner selbstgebauten Word Clock steht nichts mehr im Weg!

Am meisten gefallen haben mir die einzelnen Labortage. Die Theorie wurde dabei immer direkt mit einem praktischen Teil kombiniert, wodurch wir unser neues Wissen sofort anwenden und vertiefen konnten. Jedes Labor war einzigartig, weshalb es auch nie langweilig wurde!

Besonderer Dank geht dabei an Ali, der uns Woche für Woche mit seiner Art und seinen spanneden Vorträgen begeisterte und uns bis zum Schluss bei unseren Projekten unterstützte. 
Dank Ali wird das Anwendungsfach ein Highlight meines Studiums bleiben, denn ohne ihn wäre Sketching with Hardware nur halb so toll. :) 

### Abschlusspräsentation Übungsprojekt

Der Höhepunkt des ersten Semesters war für mich das Übungsprojekt. 
Auch wenn wir lange Nächte im Labor verbrachten, wegen kleinen Fehlern fast wahnsinnig wurden und Ali an den Rand der Verzweiflung brachten (Tschuldigung :D), war die Abschlusspräsentation ein voller Erfolg!
Die Projekte wurden dabei in Form einer kleinen Messe vorgestellt. Dazu sollten wir ein Poster entwerfen, welches dann über unseren kleinen Stand gehängt wurde.

{{< figure src="../pictures/Poster.png" width="80%"height="60%">}}

Besonders spannend war es zu sehen, wie unterschiedlich die Umsetzung der einzelnen Projekte war - 
Und nicht nur die Studenten, auch die Besucher interessierten sich sehr für unsere Projekte. 
Es machte sehr viel Spaß das Projekt zu präsentieren und den Prozess dahinter zu erläutern.
Die Besucher interessierten sich vorallem für die Technik und den 3D-Druck. 

{{< figure src="../pictures/Verkabelung.jpg" width="60%"height="60%">}}
{{< figure src="../pictures/offen.jpeg" width="60%"height="40%">}}
{{< figure src="../pictures/Gehaeuse.jpeg" width="60%"height="60%">}}

Das Highlight für alle war natürlich das Testen und Spielen des Gameboys.
Ich bekam durchweg begeisterte Gesichter zu sehen und durfte mich über positives Feedback für meinen Controller-Gameboy freuen.

{{< rawhtml >}} 
<video width=60% controls autoplay>
    <source src="../pictures/demo.mp4" type="video/mp4">
    Your browser does not support the video tag.  
</video>
{{< /rawhtml >}} 

### Ausblick

Ich freue mich schon sehr auf das nächste Semester von Sketching with Hardware und kann es kaum erwarten, die verschiedenen Projektideen zu sehen. Das Projekt soll sich mit der Lösung einer Problemstellung beschäftigen. Dabei ist uns überlassen, ob wir eigene Alltagsprobleme oder Probleme von Verwandten oder Bekannten lösen möchten.
Eine genaue Projektidee habe ich bisher noch nicht, werde aber nach Problemen im Alltag Ausschau halten.

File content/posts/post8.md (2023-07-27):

---
title: "01. Das zweite Semester - Semesterverlauf"
date: 2023-07-04T14:54:18+01:00
featured_image: "/pictures/loetplan.jpg"
show_reading_time: true
draft: false
---

### Rückblick
Zu Beginn des Semester ging es nach einer kurzen Einführung direkt auf die Suche nach einer Projektidee. Dazu wurden uns "Must-Haves" und "Should-Haves" vorgestellt, welche wir weitesgehend in unseren Projekten umsetzen sollten. 

Da ich noch immer beigstert vom Design der WordClock war, entschied ich mich dafür, eine erweiterte Version der Wordclock zu bauen: Den WordClockanizer. 
Dieser sollte neben der Uhrzeit noch den Wochentag, die Kalenderwoche und die Termine meines Apple-Kalenders der kommenden 7 Tage anzeigen. 
Um die Kalenderdaten auszulesen, überlegte ich mir, meinen Apple-Kalender zunächst einmal in einen Google-Kalender zu übertragen und diesen dann mithilfe der API auszulesen. Die Kalenderdaten sollten auf einem Display oder als Lauftext auf LED-Matrizen angezeigt werden.
Unsere Projekt-Idee und einen groben Zeitplan sollten wir dann beim Projekt-Pitch vorstellen.

{{< figure src="../pictures/projektpitch1.png" width="60%"height="60%">}}
{{< figure src="../pictures/projektpitch2.png" width="60%"height="60%">}}

Zudem wurden uns einige Tools an die Hand gegeben, welche wir verwenden durften um unser Projekt zu planen. Ich entschied mich zunächst einmal für Notion, da ich damit bereits gearbeitet hatte, jedoch merkte ich sehr schnell, dass der klassische Weg mit Post-Its, Kalender, Notizen und Checkliste sich besser für mich eignete. Somit plante ich mein komplettes Projekt letztendlich ohne die vorgestellten Tools.

Nach abgeschlossener Planung ging es dann direkt ins Labor, um eine Teileliste für das Projekt und eine grobe Skizze zu entwerfen.

{{< figure src="../pictures/skizze1.jpg" width="60%"height="60%">}}

{{< figure src="../pictures/skizze2.jpg" width="100%"height="60%">}}

### Projektphase

Der WordClockanizer sollte aus 3 Schichten bestehen: Einer Vorderseite aus Holzfurnier, einem 3D-gedruckten Rahmen und einer 3D-gedruckten Rückseite. 
Der Plan war, dass sowohl die LED-Matrizen als auch die Buchstaben der Wordclock durch das Furnier scheinen, jedoch zeigte sich später, dass das Furnier ebenfalls cutten musste. 
Das Furnier sollte dann auf den Rahmen geklebt werden, welcher aus schwarzem Fillament gedruckt werden sollte.
In den unteren Abschnitt des Rahmens sollte eine 3D-gedruckte Matrizenhalterung samt LED-Matrizen eingesetzt werden, in den oberen Abschnitt eine lasergecuttete Buchstabenplatte samt LED-Stripe.
Dazu sollten die Buchstaben der Wordclock in 3mm dicke Spanplatten gecuttet werden. Damit die LED's nur durch die jeweils richtigen Buchstaben leuchten, musste ich dann noch ein Raster und eine Halterung für den LED-Stripe erstellen. 
Das Raster sollte aus schwarzem Fillament 3D-gedruckt werden. In das Raster sollten dann 3D-gedruckte Quadrate aus transparentem Fillament eingesetzt werden, um das Licht etwas zu streuen und gleichzeitig die Lämpchen zu verstecken.
Für die LED-Stripe-Halterung überlegte ich mir Schlitze in eine weitere Spanplatte zu cutten, sodass der LED-Stripe einfach durchgefädelt werden konnte. 
Die Rückseite sollte dann aus durchsichtigem Fillament 3D-gedruckt werden und anschließend mit dem Rahmen verschraubt werden.
Das Projekt sollte außerdem noch einige weitere Features bieten. So wollte ich die Farben der Uhr mit einem Button wechseln können. Zudem sollte die Uhr natürlich möglichst stromsparend sein. Um dies zu erreichen wollte ich zum Beispiel, dass die Uhr, je nach Helligkeit, von selbst heller und dunkler wird. Zudem sollte man einzelne Komponenten, wie die LED-Matrizen oder das geplante Ambient-Light seperat ein- und ausschalten können.
Um die gesamte Uhr auszuschalten sollte dann noch ein Kippschalter angebracht werden.

##### 3D-Modelle
{{< figure src="../pictures/rahmen.png" width="60%"height="60%">}}
{{< figure src="../pictures/matrizenhalterung.png" width="60%"height="60%">}}
{{< figure src="../pictures/raster.png" width="60%"height="60%">}}
{{< figure src="../pictures/raster_innen.png" width="60%"height="60%">}}
{{< figure src="../pictures/hinten.png" width="60%"height="60%">}}

##### Lasercut
{{< figure src="../pictures/lasercut1.jpeg" width="60%"height="60%">}}

Während ich auf die erste Bestellung wartete, erstellte ich die Modelle der Matrizenhalterung und des Rasters, sowie die Datei um die Buchstabenplatte zu cutten.
Dann ging es auch schon ans Coden der ersten Komponenten. Ich schrieb zunächst einmal einen Codeschnipsel zum testen des LED-Stripes und der LED Matrizen, welchen ich nach Ankunft der Teile sofort testete. 
Der Code für den LED-Stripe funktionierte auf anhieb, während der Code für die LED Matrizen Probleme machte.
Da ich Bibliotheken verwendete, welche nicht mit meinem ESP kompatibel waren, musste ich den Code also umschreiben und eine andere Bibliothek verwenden. 
In der Zwischenzeit startete ich schonmal den Druck der ersten Komponenten und cuttete mit dem Lasercutter die Buchstabenplatte. 

{{< figure src="../pictures/druck.jpeg" width="60%"height="60%">}}
{{< figure src="../pictures/lasercut2.jpeg" width="60%"height="60%">}}

Das cutten nahm etwa 7 Stunden in Anspruch, weshalb ich währenddessen weiter am Code schreiben konnte.
Um die genaue Uhrzeit zu bekommen und später auf dem LED-Stripe anzuzeigen, verwendete ich ein RTC-Modul. Der Code dafür war relativ simpel, da man die LED's nur zur jeweiligen Uhrzeit ein- und ausschalten musste. 
Der Code für die Kalenderdaten gestaltete sich dafür aber umso schwieriger. 
Da man die Kalenderdaten nicht so einfach direkt aus dem Apple-Kalender auslesen konnte, musste ich meinen Kalender zunächst in einen Google-Kalender übertragen.
Die Daten werden dann mit einem Google Apps Skript ausgelesen und anschließend bereitgestellt.
Da die Matrizen nicht mit Umlauten umgehen konnten, mussten diese dann noch herausgefiltert und ersetzt werden. 
Zudem wandelte ich die Buchstaben hier in Großbuchstaben um, sodass sie später besser zur Font der Wordclock passten. 
Ebenso passte ich deshalb auch die Font der LED-Matrizen an.

##### Kalenderdaten

{{< figure src="../pictures/kalender_desktop.png" width="100%"height="60%">}}
{{< figure src="../pictures/applekalender.png" width="60%"height="60%">}}
{{< figure src="../pictures/kalenderdaten2.png" width="60%"height="60%">}}

##### Font

{{< figure src="../pictures/font.png" width="100%"height="80%">}}

Als letztes programmierte ich dann noch 3 Buttons und einen Helligkeitssensor.
Mit einem der Buttons sollte das Ambient-Light, mit einem weiteren Button die LED-Matrizen ein- und ausgeschaltet werden können.
Der dritte Button sollte die Farben der LED's verändern und der Helligkeitssensor sollte die Helligkeit der LED's zur jeweiligen Tageszeit anpassen.
Da ich jedoch nur noch zwei Pin's, einen digitalen und einen analogen, zur Verfügung hatte, musste ich dabei etwas improvisieren.
Um die verschiedenen Signale zu erfassen verwendete ich mehrere verschiedene Widerstände, die zwischen Buttons und den Helligkeitssensor gelötet wurden. Somit konnte ich dann zwei Butons und den Sensor an den analogen Pin anschließen. Der letzte Button wurde einfach an den digitalen Pin angeschlossen.

Unsere fertigen Projekte wurden dann auf dem Streiflicht vorgestellt.

{{< figure src="../pictures/WordClockanizer_Plakat.png" width="100%"height="80%">}}

### Fertigungsverfahren

Für mein Projekt verwendete ich verschiedene Fertigungsverfahren. Während einige Teile des Gehäuses 3D-gedruckt wurden, wurden andere Teile lasergecuttet. 
Der 3D-Druck hatte hierbei vorallem den Vorteil, dass man größere Teile unbeaufsichtigt drucken lassen konnte. Zudem konnten die Teile auf Millimeter genau gefertigt werden. In der Praxis machten die Drucker jedoch häufiger Probleme, sodass manche Drucke mehrmals gestartet werden mussten, bis man ein brauchbares Bauteil bekam. Ein weiterer Nachteil war dabei, dass die Drucke im Nachhinein nicht mehr wirklich bearbeitet werden konnten, falls es an manchen Stellen zu Ungenauigkeiten kam.

Der Lasercutter hingegen musste die ganze Zeit über beobachtet werden, sodass man in der Zwischenzeit nicht einfach weggehen konnte. Die Buchstabenplatte musste so z.B ganze 8 Stunden lang beobachtet werden.
Ein Vorteil des Lasercutters war jedoch, dass dieser die Teile bei richtiger Einstellung immer genau cuttete. Zudem konnten die Spanplatten im Nachhinein noch geschliffen oder gesägt werden, falls etwas doch nicht ganz passte.

### Motivation, Fazit und Feedback

Da ich bereits lange Zeit plante die WordClock zu bauen, war die Motivation natürlich sehr groß, so verbrachten wir 6 Wochen lang fast Tag und Nacht im Labor, um an unseren Projekten zu basteln. Der Gedanke, die selbstgebaute Uhr später im Zimmer stehen zu haben, erhöhte die Motivation zudem enorm.

Aus Sketching with Hardware nehme ich vorallem mit, wie viel Spaß die Kombination aus Software und Hardware machen kann. Da wir im Studium bisher kaum praktische Anteile hatten und diese dann nur Softwareseitig waren, war es eine tolle Abwechslung auch mal mit der Hardware in Berührung zu kommen. 
Persönlich nehme ich vorallem mit, wie viel Spaß es macht selbst eigene Projekte umzusetzen und sich Soft- und Hardwareseitig mit Problemstellungen auseinander zu setzen. Nach Sketching with Hardware bin ich nun dazu in der Lage, auch komplexere Projekte selbstständig umzusetzen.
Auch für meine berufliche Zukunft glaube ich, dass es sicherlich von Vorteil war, diese Schnittstelle zwischen Soft- und Hardware kennengelernt zu haben.
Außerdem ist es bestimmt von Vorteil, mit einem Lötkolben, 3D-Drucker und Lasercutter umgehen zu können.

Alles in allem bin ich sehr zufrieden mit dem Kurs und auch mit meinem fertigen Projekt. 
Für zukünftige Jahrgänge wünsche ich mir eventuell neue 3D-Drucker, um den zukünftigen Teilnehmern die Arbeit zu erleichtern. Zudem wäre es toll mehrere, gut funktionierende Lötkolben zu haben. Bei einigen wurden die Spitzen, auch wenn leider erst sehr spät, jedoch schon ausgewechselt.
Der größte Kritikpukt in diesem Semester war jedoch die sehr knapp bemessene Zeit, die wir für unsere Projekte hatten.
So wurde ich, trotz straffem Zeitplan und fast täglichen Nachtschichten im Labor, zum Beispiel erst kurz vor der Vorstellung des Projekts fertig. 

Der Projekt-Pitch war erst Anfang Mai, sodass wir bis zur Vorstellung der Projekte leider nur 6 Wochen hatten.
Eine Idee wäre, die Themenwahl und den Projekt-Pitch schon auf das Ende des ersten Semesters zu schieben, sodass das Projekt schon über die Semesterferien geplant werden kann und direkt zu Semesterbeginn mit dem Projekt gestartet werden kann. 
Die klare Trennung von Theorie im ersten Semester und dem großem Projekt im zweiten Semester waren sehr Hilfreich. Das Übungsprojekt im ersten Semester hat zudem schonmal einen guten Einblick in mögliche Probleme für das große Projekt gegeben.

Sketching with Hardware ist und wird das Highlight meines Studiums bleiben. Nicht nur dank meiner Kommilitonen, sondern auch dank Ali werde ich das Fach lange mit guten Erinnerungen im Hinterkopf behalten.

### Projekt: WordClockanizer

Der "WordClockanizer" sollte das klassische Design einer WordClock mit einem intelligenten Kalender verbinden, um einen Überblick über anstehende Termine zu ermöglichen. 
Eine WordClock ist eine Uhr, die anstelle von Zahlen Wörter oder Buchstaben verwendet, um die Uhrzeit anzuzeigen. 
Indem die Idee mit einem intelligenten Kalender verknüpft wird, schafft sie eine neue und einzigartige Anwendung für ihre Benutzer.

#### Features

- **WordClock**: Der obere Teil des WordClockanizers zeigt mithilfe von LED'S den Wochentag und die Uhrzeit in Worten an. Die genaue Uhrzeit wird durch ein RTC-Modul beibehalten, welches eine eigene Batterie verwendet, sodass die Uhrzeit auch richtig angezeigt wird, falls die Stromverbindung einmal getrennt wird.

- **Kalender**: Im unteren Teil werden die Termine der nächsten 7 Tage des Apple- oder Google-Kalenders als Lauftext auf LED-Matrizen angezeigt. Der Kalender wird zwei mal täglich aktualisiert, sodass er immer aktuell ist.

- **Farbwechsel**: Mit einem Button an der oberen Seite des WordClockanizers kann die Farbe der LED's gewechselt werden.

- **Ambient-Light**: Das integrierte Ambient-Light schafft Behaglichkeit und Atmosphäre. Die Farbe des Ambient-Lights wird analog zur Farbe der WordClock gewechselt.

- **Stromsparend**: Mit einem Kippschalter kann die gesamte Uhr ein- und ausgeschaltet werden. Zudem können das Ambient-Light sowie die LED-Matrizen mit einem Button seperat ein- und ausgeschaltet werden. Ein Helligkeitssensor passt zusätzlich die Helligkeit der WordClock und der LED-Matrizen automatisch an.

- **Zugänglichkeit**: Die Rückseite der Wordclock ist mit dem Rahmen verschraubt, sodass die Technik leicht zugänglich ist. So können z.B. die Batterie des RTC-Moduls oder der LED-Stripe leicht ausgetauscht werden.

Alle Features waren zum Zeitpunkt der Abschlusspräsentation bereits funktionsfähig, sodass im Nachhinein nichts mehr angepasst werden musste.
Lediglich der Rahmen der Uhr wurde neu gedruckt, da dieser Ursprünglich aus 3 Teilen bestand.

#### Alter Rahmen
{{< figure src="../pictures/Rahmen_oben(alt).jpeg" width="60%"height="60%">}}
{{< figure src="../pictures/Rahmen_rechts(alt).jpeg" width="60%"height="60%">}}

#### Neuer Rahmen
(Oberseite mit ON/OFF Kippschalter, Helligkeitssensor und Farbwechselbutton)
{{< figure src="../pictures/Rahmen_oben(neu).jpeg" width="60%"height="60%">}}

(Rechte Seite mit Button für Ambient-Light und LED-Matrizen)
{{< figure src="../pictures/Rahmen_rechts(neu).jpeg" width="60%"height="60%">}}

(Linke Seite mit Anschluss für Netzteil)
{{< figure src="../pictures/Rahmen_links(neu).jpeg" width="60%"height="60%">}}

#### Innenseite
{{< figure src="../pictures/innenseite.jpeg" width="60%"height="60%">}}

#### Vorderseite
{{< figure src="../pictures/Wordclock.jpeg" width="60%"height="60%">}}

#### Funktionen
{{< rawhtml >}} 
<video width=60% controls autoplay>
    <source src="../pictures/Funktionen.mp4" type="video/mp4">
    Your browser does not support the video tag.  
</video>
<video width=60% controls autoplay>
    <source src="../pictures/Wordclock.mp4" type="video/mp4">
    Your browser does not support the video tag.  
</video>
{{< /rawhtml >}}

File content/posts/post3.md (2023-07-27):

---
title: "03. Microcontroller Labor"
date: 2022-12-06T17:31:58+01:00
featured_image: "/pictures/microcontroller.jpeg"
show_reading_time: true
draft: false
---

### Erster Tag

Am ersten Tag ging es nach einer kurzen theoretischen Einführung direkt in den praktischen Teil über.
Wir bekamen eine Kiste mit verschiedenen Bauteilen und Sensoren, verschiedene Kabel, Widerstände und einen Arduino in die Hände gedrückt. 

Zum Einstieg sollten wir verschiedene Sensoren aus der Kiste nehmen und uns überlegen, was diese für eine Funktion haben könnten.

{{< figure src="../pictures/Baukasten.png" width="60%"height="100%">}}

Im Anschluss daran, ging es dann auch schon los mit unserem "ersten Programm".
Wir schlossen den Arduino an unsere Laptops an und starteten das Programm "Blink" - da blinkte auch schon die auf dem Arduino verbaute LED.

{{< rawhtml >}} 
<video width=60% controls autoplay>
    <source src="../pictures/ErstesProgramm.mp4" type="video/mp4">
    Your browser does not support the video tag.  
</video>
{{< /rawhtml >}} 

Danach versuchten wir außerdem noch diverse externe LED´s anzuschließen. Dazu nahmen wir eine Steckplatine und ein paar Kabel zur Hilfe. 
Ich schaltete zunächst zwei LED´s in Reihe und anschließend parallel, wobei die parallel geschalteten LED´s natürlich viel heller leuchteten.

{{< rawhtml >}} 
<video width=60% controls autoplay>
    <source src="../pictures/Reihenschaltung.mp4" type="video/mp4">
    Your browser does not support the video tag.  
</video>
<video width=60% controls autoplay>
    <source src="../pictures/Parallelschaltung.mp4" type="video/mp4">
    Your browser does not support the video tag.  
</video>
{{< /rawhtml >}} 

Im nächsten Schritt kamen dann erstmals die verschiedenen Sensoren zum Einsatz. 
Als erstes versuchte ich einen Touchensor zu benutzen. Bei Berührung sollte dieser eine LED ein- und ausschalten.

{{< rawhtml >}} 
<video width=60% controls autoplay>
    <source src="../pictures/TouchSensor.mp4" type="video/mp4">
    Your browser does not support the video tag.  
</video>
{{< /rawhtml >}} 

Da der Sensor aber nur bedingt funktionieren wollte, musste ich mir etwas anderes einfallen lassen.
Ich stieg also auf einen einfachen Button um. 
Das Skript funktionierte auf Anhieb und die LED machte das was ich wollte.

{{< rawhtml >}} 
<video width=60% controls autoplay>
    <source src="../pictures/Button.mp4" type="video/mp4">
    Your browser does not support the video tag.  
</video>
{{< /rawhtml >}}  

Zum Abschluss des ersten Tages versuchten wir noch zu Zweit einen Motor zum Laufen zu bekommen. 
Der Motor hatte zunächst aber andere Pläne und wollte wohl erst einmal testen, ob wir das Wissen der letzten Woche auch umsetzen konnten. Es lösten sich die Drähte, woraufhin diese wieder angelötet werden mussten.
Nach bestandener Zwischenprüfung ergab sich dann auch schon das nächste Problem: 
Leider bedachten wir nicht, dass der Arduino nicht genug Strom für den Motor lieferte.
Für eine etwas kompliziert Lösung fehlte uns dann die Zeit, weshalb wir das Projekt letzten Endes verwerfen mussten.

{{< figure src="../pictures/Motor.png" width="100%"height="100%">}}

### Zweiter Tag

Am zweiten Tag des Microcontroller Labors wurden serielle Kommunikation und Interrupts besprochen.
Leider habe ich an diesem Tag nicht an der Vorlesung teilnehmen können, da ich krank war. Somit konnte ich kein neues Projekt beginnen.  

### Dritter Tag

Am letzten Tag durften wir uns nach einer abschließenden, kurzen Theorie-Stunde wieder dem Baukasten widmen. 
Ich entschied mich dafür, die serielle Kommunikation etwas zu vertiefen. Dazu nahm ich vier LED-Matrizen, welche ich miteinander verband.
Das Ziel war es, mit einer Bibliothek meinen Spitznamen abzubilden, was jedoch irgendwie nicht ganz klappen wollte. Statt Buchstaben erschienen einzelne leuchtende LED´s, welche aufgrund eines Wackelkontakts aber immer mal wieder verschwanden.

Letzten Endes entschied ich mich dann dazu, nur eine Matrix zu benutzen und die Bibliothek zu verwerfen. Die Verkabelung stellte sich als ziemlich einfach heraus.

{{< figure src="../pictures/Schaltung.png" width="100%"height="100%">}}

Da ich noch immer einen Buchstaben abbilden wollte, entschied ich mich dazu, ein "A" hart zu coden.
Mit folgendem Code kam ich endlich zu meinem Ziel:

{{< figure src="../pictures/Code.png" width="100%"height="100%">}}
{{< figure src="../pictures/Buchstabe.png" width="60%"height="100%">}}

### Funktionsweise und Nutzen von Interrupts und Sleep-Modis

Ein letztes wichtiges Thema bei der Benutzung von Microcontrollern sind Interrupts und Sleep-Modi.

Interrupts dienen zur zur Überwachung von auftretenden Events während der Laufzeit. Sobald ein Signal bemerkt wird, unterbricht ein Interrupt einen laufenden Prozess und führt eine vorgegebene Handlung aus. Im Anschluss daran springt er zum ursprünglichen Punkt zurück und setzt den unterbrochenen Prozess fort.

Der Vorteil daran: Interrupts machen den Prozessor für andere Dinge frei, während auf ein tatsächliches Ereignis gewartet wird. So muss im loop nicht ständig überprüft werden, ob sich etwas verändert hat!

{{< figure src="../pictures/Interrupts.png" width="70%"height="100%">}}

Sleep-Modi wiederum können den Prozessor in eine Art "Schlafmodus" versetzen. Der Vorteil ist vorallem Energie zu sparen, wenn gerade nichts passiert. Dazu gibt es folgende Methoden:

{{< figure src="../pictures/SleepModi.png" width="100%"height="100%">}}

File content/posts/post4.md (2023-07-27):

---
title: "04. Mechanik Labor"
date: 2023-01-30T13:55:59+01:00
featured_image: "/pictures/mechanik.jpg"
show_reading_time: true
draft: false
---

Im heutigen Labor beschäftigten wir uns mit der Mechanik. Wie immer begann das Labor mit einer kurzen theoretischen Einführung, in der wir die grundlegenden Funktionsweisen von Maschinen kennenlernten. 
Maschinen werden vor allem für die Kraftumwandlung und -verstärkung, die Energieübertragung und -umwandlung, aber auch für die Geschwindigkeitserhöhung verwendet.
Klassische Mechanismen sind zum Beispiel Hebel, Flaschenzüge, Gewinde, Zahnräder, geneigte Flächen und Räder und Achsen.
Auch im Alltag benutzen wir täglich Maschinen, wie zum Beispiel Fahrräder, welche Zahnräder verwenden, oder Flaschenöffner, die die Hebelwirkung nutzen.

Als nächstes ging es dann zum praktischen Teil, wo Baukästen ausgeteilt wurden, mit denen wir in Zweierteams verschiedene Getriebearten bauen durften.

### Schubkurbel

Die erste Aufgabe war es, eine einfache Schubkurbel zu bauen. Diese wandelt eine Rotationsbewegung in eine Schubbwegung um.

{{< figure src="../pictures/Schubkurbel.jpeg" width="80%"height="100%">}}
{{< rawhtml >}} 
<video width=60% controls autoplay>
    <source src="../pictures/Schubkurbel.mp4" type="video/mp4">
    Your browser does not support the video tag.  
</video>
{{< /rawhtml >}} 

### 3-Gang-Schaltgetriebe

Die nächste Aufgabe wurde dann schon etwas schwieriger. Wir sollten ein 3-Gang-Schaltgetriebe bauen, das einen schnellen, einen langsamen, und einen Rückwärtsgang hatte. 
Nach anfänglicher Skepsis und kleinen Problemen mit der korrekten Einstellung der Zahnräder gelang uns dies aber recht schnell.

{{< figure src="../pictures/Getriebe.jpeg" width="80%"height="100%">}}
{{< rawhtml >}} 
<video width=60% controls autoplay>
    <source src="../pictures/Getriebe.mp4" type="video/mp4">
    Your browser does not support the video tag.  
</video>
{{< /rawhtml >}} 

Anschließend durften wir uns dann noch eigene Projekte aussuchen, welche wir dann ebenfalls nachbauen sollten.
Wir entschieden uns als erstes für ein Scherenhubgetriebe.

{{< rawhtml >}} 
<video width=60% controls autoplay>
    <source src="../pictures/Scherenhub.mp4" type="video/mp4">
    Your browser does not support the video tag.  
</video>
{{< /rawhtml >}} 

Als letztes suchten wir uns noch das sogenannte Planetengetriebe aus.
{{< figure src="../pictures/Planetengetriebe.jpeg" width="80%"height="100%">}}
{{< rawhtml >}} 
<video width=60% controls autoplay>
    <source src="../pictures/Planetengetriebe.mp4" type="video/mp4">
    Your browser does not support the video tag.  
</video>
{{< /rawhtml >}}

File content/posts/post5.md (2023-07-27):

---
title: "05. Subtraktive Fertigung"
date: 2023-01-31T18:28:12+01:00
featured_image: "/pictures/subtraktive.jpeg"
show_reading_time: true
draft: false
---

### Einführung 

Die subtraktive Fertigung umfasst verschiedene Verfahren, bei denen Bauteile durch das Abtragen von Material gefertigt werden können. Typische Geräte sind zum Beispiel CNC-Fräsen oder Lasercutter.
Die Ausgangsmaterialien sind meist Blöcke aus Holz, Kunststoff, Acrylglas oder sogar Metall. Diese können dann z.B. durch Schneiden, Fräsen, Schleifen oder Lasern bearbeitet werden.
Zu beachten ist dabei, dass nicht jedes Material von jedem Gerät bearbeitet werden kann bzw. darf. 
So können z.B. bei der Bearbeitung von Kunstleder mit dem Lasercutter giftige Gase entstehen. 
Folgende Materialien können problemlos mit den Geräten in unserem Lab bearbeitet werden:

- Laser-Cutter: Thermoplaste, Holz, Acrylglas, Stoff
- CNC-Fräse: Harte Thermoplaste, Thermosekunststoffe

### Labor 

Um uns mit den Geräten vertraut zu machen, bekamen wir die Aufgabe, mit dem Lasercutter ein ca. 5x5 cm großes Teil unserer Wahl anzufertigen. Ich entschied mich für einen kleinen Schlüsselanhänger mit einem Bild meines Hundes.
Dazu lud ich ein Bild in Lightburn, welches ich dann in eine ovale Form und auf die gewünschte Größe brachte. 

{{< figure src="../pictures/Lightburn.png" width="100%"height="100%">}}

Nun sollte das Bild auf eine Holzplatte gelasert werden.
In mehreren Schritten versuchte ich Power und Speed so anzupassen, bis man das Bild gut auf dem Holz erkennen konnte.
Nach ca. 10 Minuten war der Schlüsselanhänger dann fertig.

{{< figure src="../pictures/Anhaenger.png" width="50%"height="50%">}}

### Projektplanung

Zum Schluss ging es dann an die Projektplanung. Zunächst fertigte ich einen groben Entwurf meines Gameboys an.
Die Idee war, eine Art Controller mit eingebautem Display zu entwerfen.

{{< figure src="../pictures/Skizze1.png" width="100%"height="50%">}}

Dieser soll aus 2 Teilen bestehen, welche später zusammengesetzt werden.
Der untere Teil ("das Gehäuse") soll dabei 3D gedruckt werden, der obere Teil ("der Deckel") soll aus einer Holzplatte bestehen, in die Aussparungen für Display, Buttons und Lautsprecher gefräst oder gelasert werden.
Somit sind später sowohl additive Fertigung als auch subtraktive Fertigung vertreten.
 
{{< figure src="../pictures/Skizze2.png" width="100%"height="50%">}}

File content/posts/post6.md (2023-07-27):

---
title: "06. Additive Fertigung"
date: 2023-02-13T14:25:02+01:00
featured_image: "/pictures/additive.jpeg"
show_reading_time: true
draft: false
---

Das Gegenstück zur Subtraktiven Fertigung ist die additive Fertigung.
Die additive Fertigung ermöglicht es, dreidimensionale Objekte aus digitalen 3D-Modellen zu drucken, indem schichtweise Material aufgetragen wird. Im Gegensatz zur subtraktiven Fertigung, wird bei der additiven Fertigung Material hinzugefügt, um ein Objekt zu fertigen. 
Es gibt verschiedene Arten von 3D-Druckern, darunter SLA (Stereolithography), FDM (Fused Deposition Modeling), SLS (Selective Laser Sintering) und SPD (Selective Powder Deposition) -Drucker.

Im Labor stehen uns verschiedene FDM-Drucker zur Verfügung.

### Software
Bevor mit dem Druck gestartet werden kann, muss zunächst einmal eine Reihe an Programmen heruntergeladenen werden.
Zum Erstellen des 3D-Models kann dabei sowohl CAD-Software (wie Fusion 360) als auch Mesh-Bearbeitungssoftware (wie Blender) verwendet werden.
Mit CAD-Software können Modelle millimetergenau mithilfe von geometrischen Formen und 3D-Körpern erstellt werden, wohingegen Mesh-Bearbeitungssoftware für komplexere oder organische Objekte benutzt werden kann.
Zudem benötigt man ein weiteres Programm, um das fertige Modell dann auch drucken zu können.
Für unseren Drucker verwendeten wir "UltiMaker Cura". 

Um ein wenig mit den Programmen vertraut zu werden, bekamen wir die Aufgabe, eine Halterung für ein Türschild zu entwerfen.
Dieses designten wir in "Fusion 360". Anschließend muss das Modell in eine Mesh-Datei umgewandelt werden. Dazu muss sie als ".stl" Datei exportiert werden, welche dann in "Ultimaker Cura" geladen wird.
Zuletzt muss die Datei dann noch "gesliced" werden. Dabei wird sie für den 3D-Druck vorbereitet und in Schichten unterteilt.
Zudem können dann noch verschiedene Einstellungen vorgenommen werden, wie die Geschwindigkeit, ob Stützstrukturen verwendet werden sollen, oder wie fein gedruckt werden soll.

{{< figure src="../pictures/Halterung1.png" width="80%"height="100%">}}

### Funktionsweise von FDM-Druckern
FDM-Drucker arbeiten durch schichtweises Auftragen von Filament auf ein Druckbett.
Das Filament wird dabei durch einen Extruder erwärmt, bis es schmilzt und flüssig wird.
Das flüssige Filament wird durch eine Düse auf das Druckbett extrudiert, um eine Schicht des 3D-Modells zu erstellen.
Der Druckkopf oder das Druckbett bewegen sich dann vertikal und wiederholen diesen Prozess, indem jede Schicht des Modells nacheinander aufgebaut wird.
Sobald das Drucken abgeschlossen ist, wird das 3D-Objekt vom Druckbett entfernt.

{{< figure src="../pictures/Drucker.jpeg" width="50%"height="50%">}}

### Arten von Druckkopf Sytemen
Dabei gibt es zwei verschiedene Arten von Druckkopf Systemen, "Bowden tube extrusion system", bei dem der Extruder weiter hinten, seperat vom Druckkopf, angebracht wird und "Direct-Drive-Extruder", bei dem der Extruder direkt am Druckkopf sitzt.
Beide Systeme bieten jeweils Vor- und Nachteile, so ist der Bowden-Extruder schneller und weniger anfällig für rissige Modelle, während der Direct-Drive-Extruder dafür flexible Materialien drucken kann und das Setup und der Materialwechsel hier deutlich einfacher sind.

### Fehler beim 3D-Druck

Die Qualität des gedruckten Objekts hängt von verschiedenen Faktoren, wie z.B. der Schichtdicke, der Temperatur des Extruders, der Geschwindigkeit des Druckkopfes und der Art des verwendeten Filaments, ab. 
Dadurch kann es zu einigen Fehlern beim drucken kommen. 3 Gängige Fehler sind:

- Warping: Der Druck hebt sich an Ecken vom Boden ab, verzieht sich und wölbt sich nach oben. Dagegen kann helfen, die Temperatur des Druckbetts zu erhöhen oder zusätzlichen Kleber zu verwenden.
- Bridging: Der Drucker druckt Verbindungen zwischen zwei Punkten, wie zum Beipsiel eine Brücke auf zwei Brückenpfeiler. Dadurch muss quasi in die Luft gedruckt werden. Dabei neigt die Verbindung bei großen Abständen dann oft zum durchhängen. Um das zu verhindern müssen gleich mehrere Dinge beachtet werden: Die Layer Höhe muss verringert werden, die Geschwindigkeit muss verringert werden und die Kühlung muss erhöht werden.
- Blobs: Der Druck bekommt unschöne Kanten oder Hubbel an einer Stelle. Das kann verhindert werden, indem die Layer Start- und Stoppositionen randomisiert werden.

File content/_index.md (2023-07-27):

---
title: "Sketching with Hardware I + II"
description: "Blog des Anwendungsfachs Sketching with Hardware im WS 2022/23 und SS2023 an der Universität Ulm"
# 1. To ensure Netlify triggers a build on our exampleSite instance, we need to change a file in the exampleSite directory.
theme_version: '2.8.2'
# featured_image: "/pictures/hintergrund.jpeg"
---

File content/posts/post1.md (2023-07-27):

---
title: "01. Vorstellung"
date: 2022-11-03T13:59:50+01:00
show_reading_time: true
draft: false
---

### Vorstellung

Hallo, ich bin Manu und ich studiere Medieninformatik im 5. Semester. Schon als ich klein war habe ich gerne gebastelt und zusammen mit meinem Vater verschiedene Sachen gebaut. Als wir dann im Rahmen des Studiums ein Anwendungsfach wählen sollten, entschied ich mich für Sketching with Hardware. Aufmerksam darauf wurde ich durch einige Kommilitonen.

Da ich bisher immer nur mechanisch gebaut habe, erhoffe ich mir von dem Fach auch praktische Fähigkeiten vorallem im technischen Bereich zu erlangen. Am meisten freue ich mich auf das 3D-Drucken und das arbeiten mit Arduinos.

### Wunschprojekt

Wenn ich alle Fähigkeiten hätte, würde ich mir verschiedene Smart-Home Systeme bauen. Da es ziemlich teuer wäre, sein ganzes Haus zu einem smart-Home umzurüsten, würde ich zum Beispiel einen elektrischen Rolladen, Vorhänge die man per Knopfduck öffnen und schließen kann, smarte Heizkörperthermostate, automatisch an- und ausschaltendes Licht oder sogar einen Staubsaugerroboter.

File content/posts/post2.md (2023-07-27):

---
title: "02. E-Technik Labor"
date: 2022-11-09T18:29:23+01:00
featured_image: "/pictures/loeten.jpeg"
show_reading_time: true
draft: false
---

### Löten

Nach einer kurzen Einführung über die Grundlagen der Elektrotechnik ging es im ersten Lab auch direkt zum praktischen Teil über, welcher aus zwei Teilen bestand. 

Zunächst einmal durften wir uns in Zweiergruppen am Löten versuchen. Dazu wurden uns Lötkolben, Lötzinn, Entlötlitze, Flussmittel, eine Leiterplatte und verschiedene Widerstände in die Hände gedrückt. 
{{< figure src="../pictures/loetzubehoer.png" width="60%"height="60%">}}

Die Widerstände sollten wir dann auf die Platine löten. Dazu musste zuerst Flussmittel aufgetragen werden. Danach wurde auch schon Lötzinn an die zu lötende Stelle gehalten und kurz mit dem Lötkolben erhitzt. 

{{< figure src="../pictures/loeten2.png" width="60%"height="60%">}}
{{< figure src="../pictures/loeten1.png" width="60%"height="60%">}} 

Da Löten für mich eine Premiere war, war die Spannung natürlich groß. Nach ein paar Versuchen stellte sich die Sache jedoch als nicht besonders kompliziert heraus und die Lötstellen wurden von mal zu mal besser.

{{< figure src="../pictures/resultat.png" width="100%"height="100%">}}

### Steckplatine und Messgeräte

Als nächstes ging es dann zu ein paar kleineren Versuchen mit Messgeräten im Labor. Dabei befassten wir uns mit dem Ohmschen Gesetz, Kennlinien, Leistung, Widerständen und der Strommessung.

{{< figure src="../pictures/Messung.png" width="60%"height="60%">}}

Mit einem Multimeter sollten wir dann zum Beispiel bestimmen, wie sich die Stromstärke in Abhängigkeit der angelegten Spannung verändert und daraus einen gegebenen Widerstand berechnen.

{{< figure src="../pictures/Messwerte.png" width="100%"height="100%">}}

Da ich das meiste noch aus der Schule kannte, musste die Theorie nur noch einmal kurz aufgefrischt werden. 

### Mein Projekt: RetroPie GameStation

Für das Erste Semester in Sketchen with Hardware habe ich mich für die RetroPi Gamestation entschieden.
Dazu habe ich schonmal versucht einen Schaltplan zusammen zu klicken.

{{< figure src="../pictures/Steckplatine.png" width="100%"height="100%">}}

Da ich in diesem Bereich jedoch noch keinerlei Erfahrung habe, stellte sich die Sache etwas schwerer heraus als Gedacht. So wusste ich zum Beispiel nicht, wie ich das Display anzuschließen habe, das ich später für die Ausgabe meines Gameboys benötigen werde. Des Weiteren musste ich mir mit ein bisschen Inspiration aus dem Internet weiterhelfen.

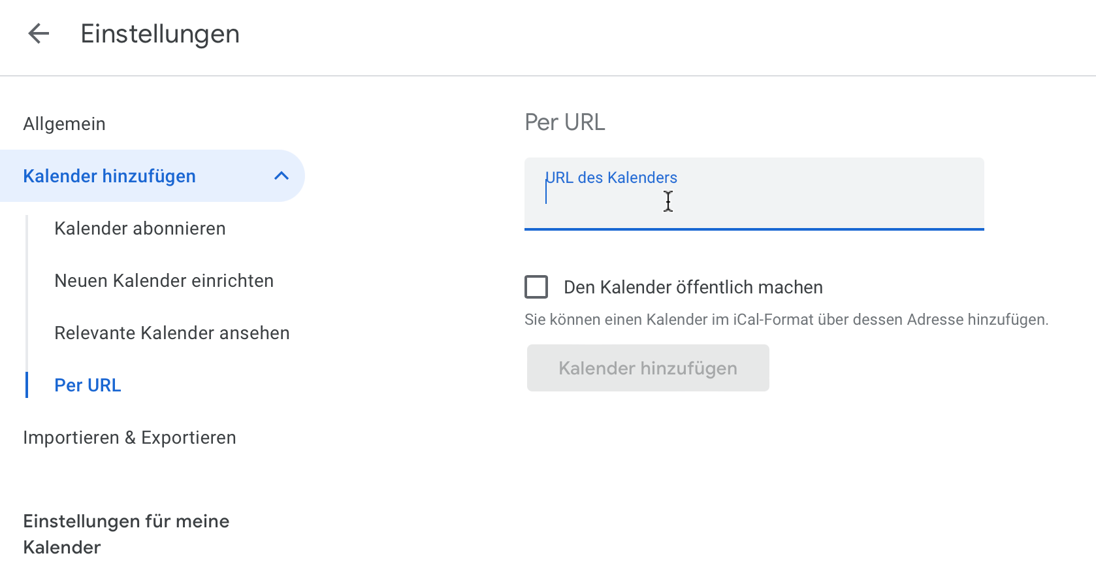
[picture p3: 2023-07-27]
content/posts/pictures/url.png

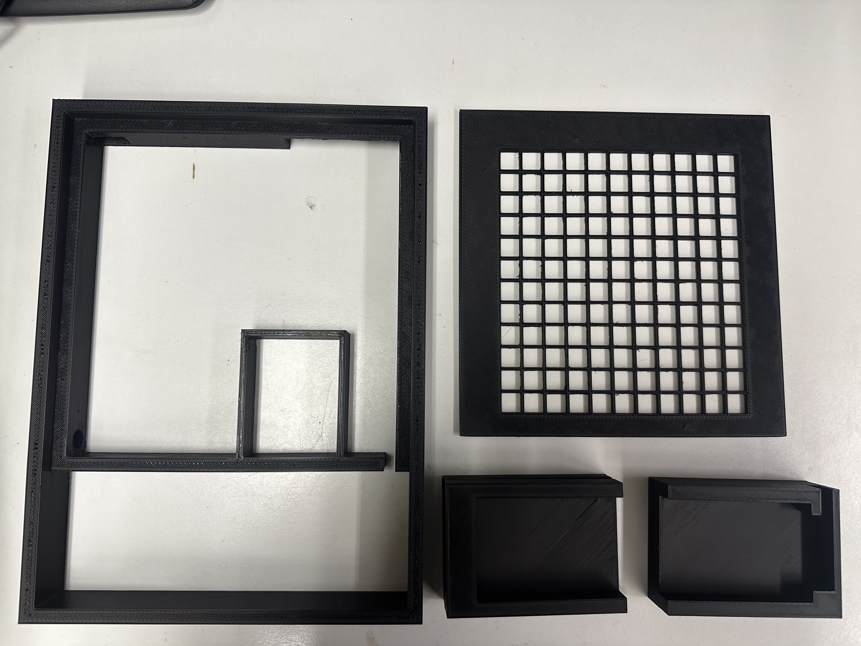
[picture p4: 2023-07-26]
content/posts/pictures/druck_schwarz.jpeg

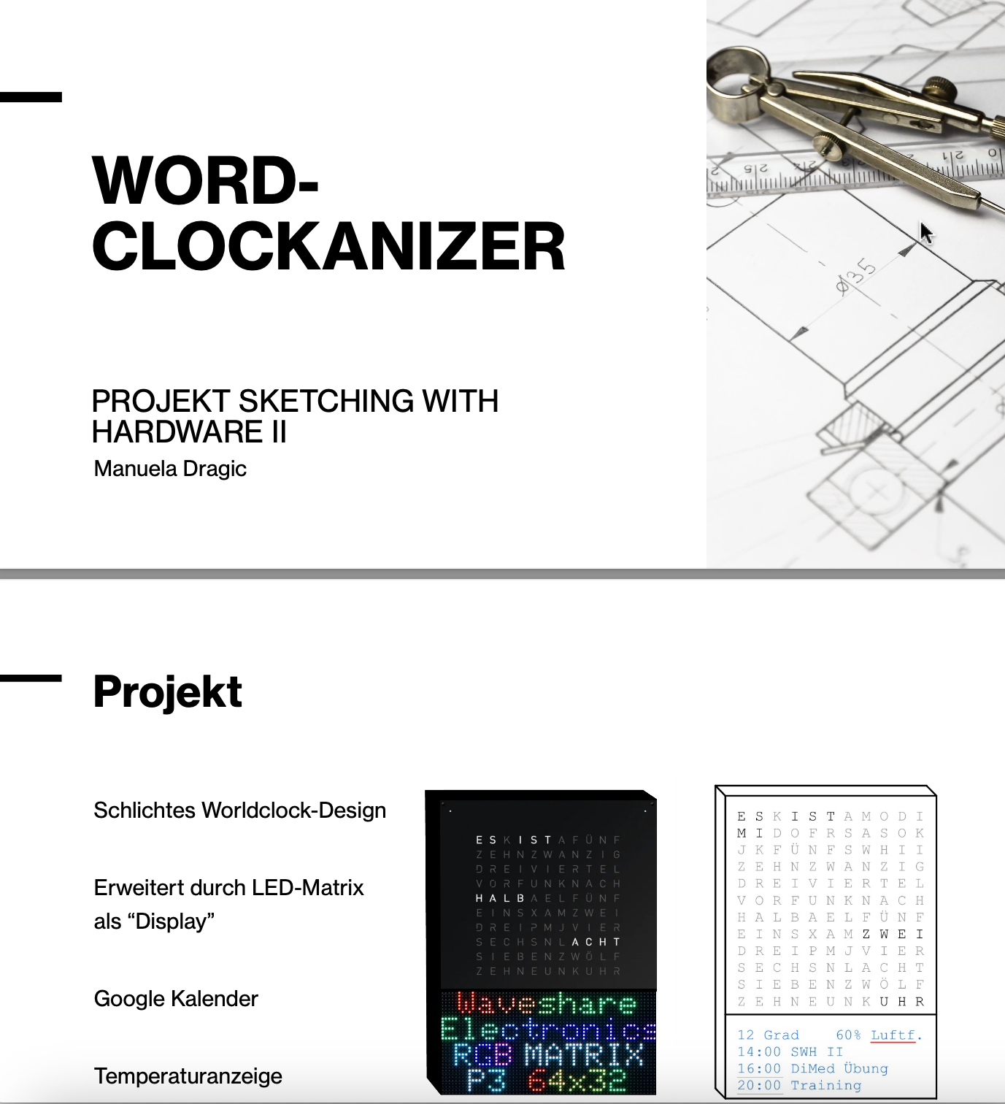
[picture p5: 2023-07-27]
content/posts/pictures/projektpitch1.png

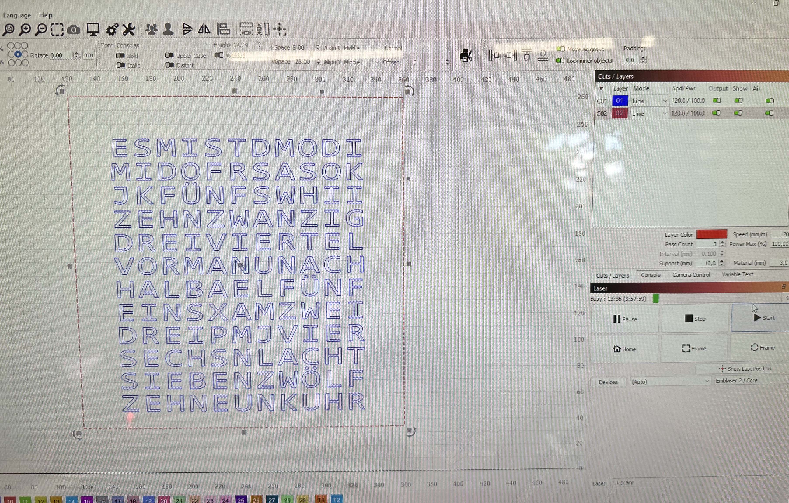
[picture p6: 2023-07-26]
content/posts/pictures/lasercut1.jpeg

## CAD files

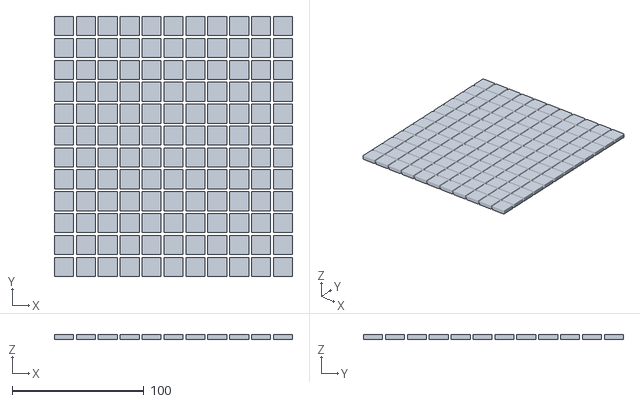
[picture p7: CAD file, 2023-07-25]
files/WordClock Rasterfüllung.stl
180.6 x 197.2 x 4.00

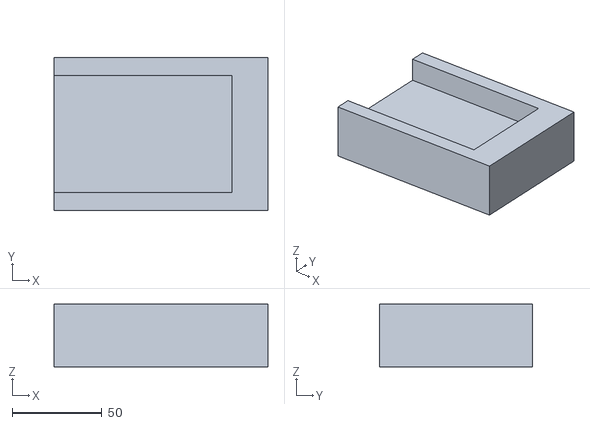
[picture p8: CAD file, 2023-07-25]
files/Matrizenhalterung_Rechts.stl
119.0 x 85.0 x 35.0

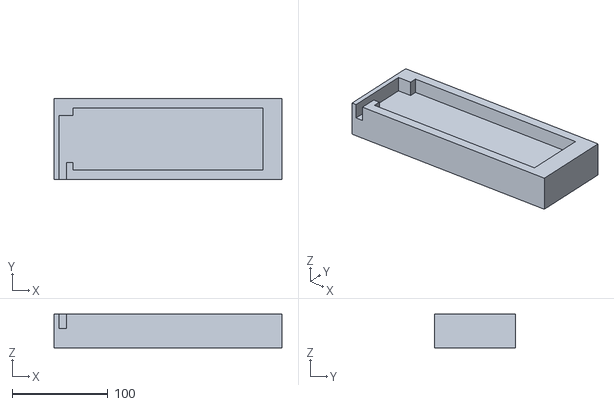
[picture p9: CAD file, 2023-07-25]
files/Matrizenhalterung.stl
238.0 x 85.0 x 35.0

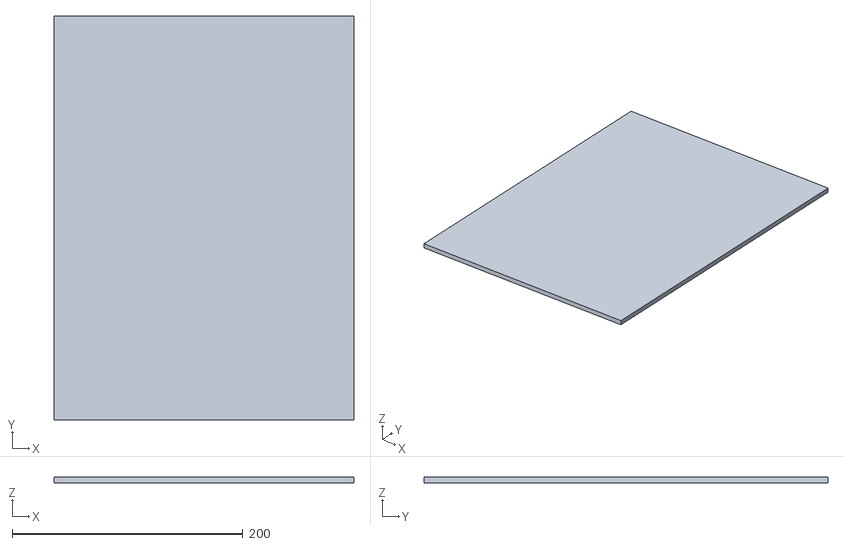
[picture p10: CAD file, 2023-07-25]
files/WordClock Rueckplatte.stl
260.0 x 350.0 x 5.00

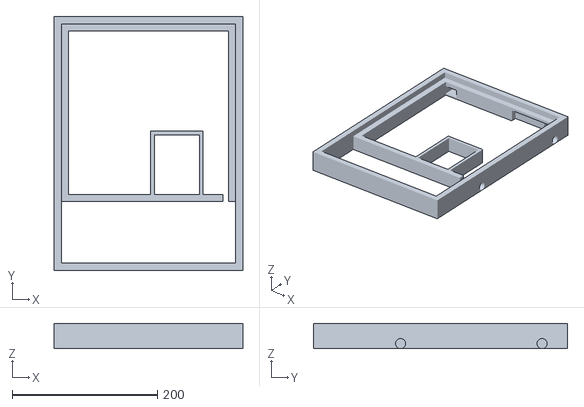
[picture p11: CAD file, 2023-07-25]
files/Word Clock Rahmen.stl
260.0 x 350.0 x 35.0

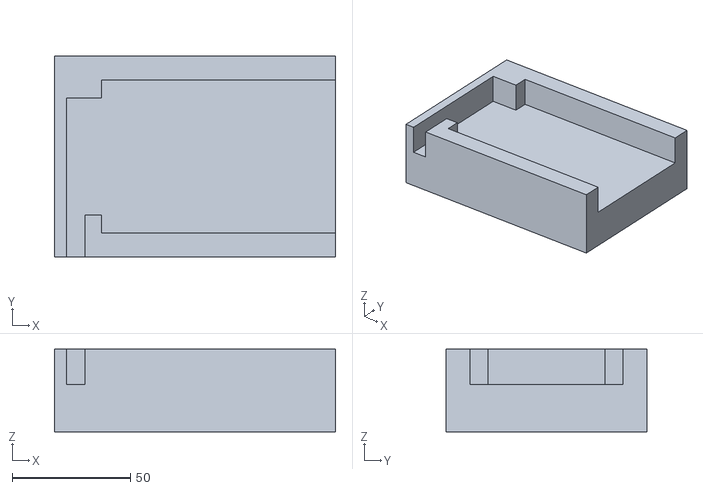
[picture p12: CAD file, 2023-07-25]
files/Matrizenhalterung Links.stl
119.0 x 85.0 x 35.0

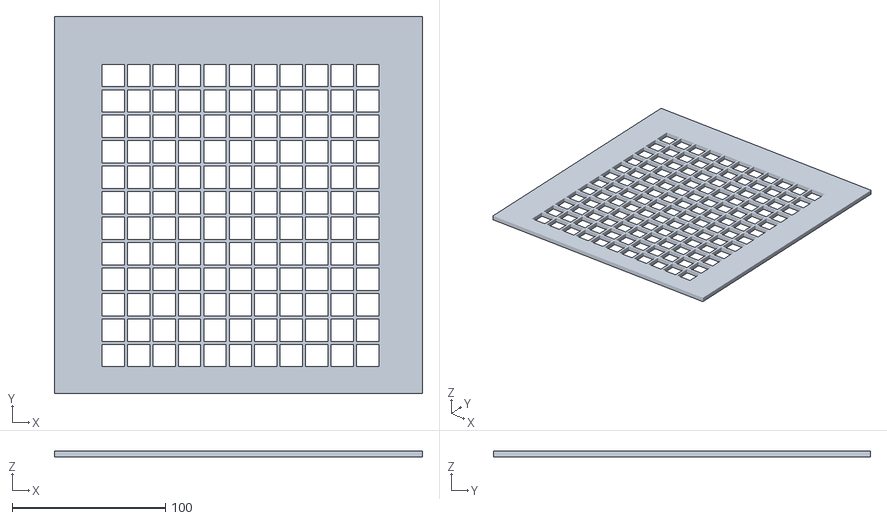
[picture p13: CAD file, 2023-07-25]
files/WordClock Raster.stl
240.0 x 246.0 x 4.00

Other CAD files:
files/Matrizenhalterung.f3d
files/Word Clock Rahmen.f3d
files/WordClock Raster.f3d
files/WordClock Rasterfüllung.f3d
files/WordClock Rueckplatte.f3d

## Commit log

2022-11-08 Erster Blogpost und Vorstellung
2023-02-19 Mechanik Lab und Additive Fertigung
2023-07-27 Semesterverlauf und Nachbauanleitung
